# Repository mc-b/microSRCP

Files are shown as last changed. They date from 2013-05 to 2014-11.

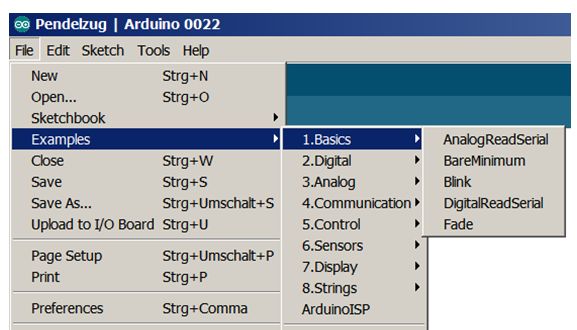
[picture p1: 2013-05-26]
microSRCP/doc/images/MicroSRCP_ArduinoIDE-howto.jpg

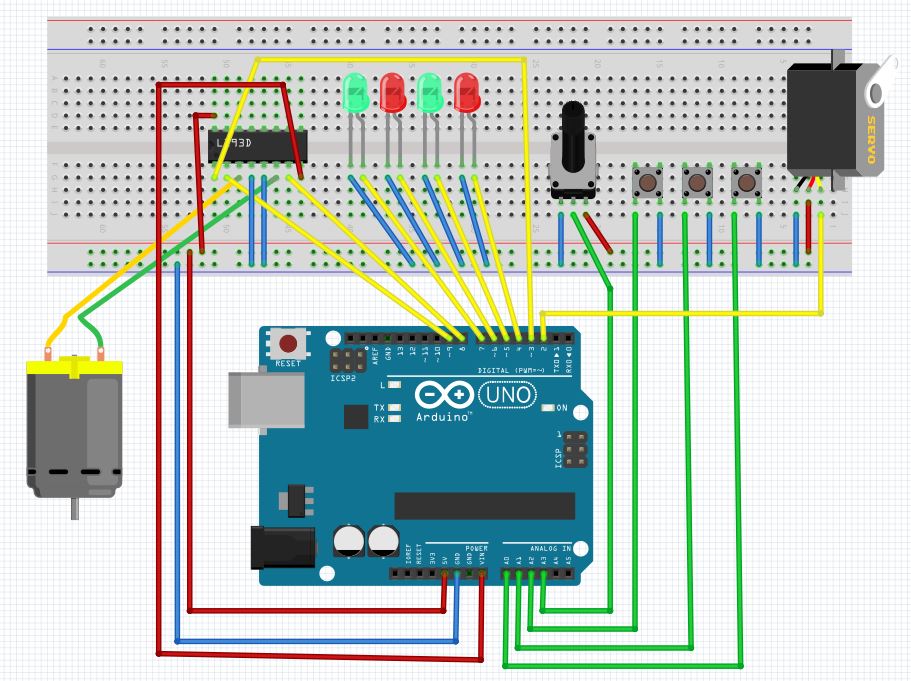
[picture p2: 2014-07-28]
microSRCP/doc/images/microSRCPV2.JPG

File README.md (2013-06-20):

microSRCP
=========

microSRCP Projekt, Steuerung einer Modelleisenbahn auf Basis der Arduino Plattform

Dieses Projekt löst das microSRCP Projekt auf berlios.de ab.

Kurzinstallation:
- Arduino Entwicklungsumgebung - http://arduino.cc/en/Main/Software, ab Version 1.0.5 installieren
- RocRail - http://wiki.rocrail.net/doku.php, zur Ansteuerung der Modelleisenbahn und der Arduino's, installieren
- Arduino Entwicklungsumgebung starten und Verzeichnis aus Menu -> Datei -> Einstellungen -> Sketchbook Speicherort notieren
- Entwicklungsumgebung beenden
- gewünschte ZIP/tar-Datei von https://github.com/mc-b/microSRCP/tags auswählen und downloaden
- ZIP/tar Datei entpacken und die Dateien aus Verzeichnis .../microSRCP/arduino in den vorher notierten Sketchbook Speicherort kopieren.
- Arduino Entwicklungsumgebung starten - unter -> Datei -> Sketchbook -> microSRCPServer wählen
- PC und Arduino mittels USB Kabel verbinden, das Betriebssystem richtet eine neue Serielle Schnittstelle ein (bei Problemen siehe www.arduino.cc)
- Unter Tools -> entsprechendes Board und Serielle Schnittstelle einstellen
- Compilieren und Uploaden des Sketches...
- RocRail starten und unter -> RocRail Eigenschaften neue srcp Zentrale mit Sub Bibliothek RS232 und gleicher Serieller Schnittstelle wie bei der Arduino Entwicklungsumgebung einrichten

Welche Arduino Boards und Shields benötigt werden steht in den entsprechenden Sketches. 

Für eine Detailierte Beschreibung, siehe https://github.com/mc-b/microSRCP/wiki.

Copyright
---------
Die Software untersteht der GNU GPL, siehe entsprechende Copyrights in 
den Sourcen. Da bedeutet u.a., sie kann frei verwendet werden, Aenderungen
und Erweiterungen muessen aber wieder frei zugaenglich sein.
Kommerzielle Produkte, ohne Offenlegung des Codes, sind damit ausgeschlossen!

Haftung
-------
Bei den Bauanleitungen bzw. irgendwelcher Software gibt es keine Haftung fuer 
irgendwelche Schaeden oder Funktionsgarantie, bitte immer nur als Anregung auffassen.
Ich hafte nicht fuer Schaeden, die der Anwender oder Dritte durch die Verwendung der 
Software oder Hardware verursachen oder erleiden. In keinem Fall hafte ich fuer 
entgangenen Umsatz oder Gewinn oder sonstige Vermoegensschaeden die bei der Verwendung 
oder durch die Verwendung dieser Programme oder Anleitungen entstehen koennen.
Und wer mit Strom umgeht, soll sich bitte bei hoeheren Spannung und Stroemen der 
Gefahren bewusst sein. Modellbahn gehoert VDE-technisch zur Kategorie Spielzeug, 
dementsprechend streng sind die Vorschriften. Siehe hierzu auch die 
Sicherheitshinweise des Fremo. 

Die Schaltungen und die Software werden als Anregung und Hilfe unter Modellbahnern
veroeffentlicht. Sie sind auf Grund von Beispielen aus dem Netz bzw. eigenen Ideen 
entstanden. Natuerlich sind sinnvolle Anregungen, Fehlermeldungen und 
Verbesserungen zu den Schaltung immer willkommen. Allerdings moechte ich aus 
gegebenen Anlass darauf hinweisen, dass ich leider keine Zeit fuer langwierige 
Diskussionen des Typs "Ich habe die Schaltung nachgebaut, warum funktioniert 
sie bei mir nicht" habe. Auch die Frage "Ich habe noch diesen oder jenen Chip 
in der Schublade, kann ich den auch verwenden", moege sich bitte jeder selbst 
beantworten. Kontaktaufnahme bitte per mail und nicht per Telefon. 
Bitte bei Problemen moeglichst exakt schildern, was wie schief geht, 
am besten mit logfiles bzw. exakter Fehlermeldung.

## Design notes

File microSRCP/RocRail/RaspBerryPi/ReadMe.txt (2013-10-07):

Konfigurations Dateien fuer RaspBerryPI
=======================================

Installation
------------
- Standard mittels NOOBS - http://www.raspberrypi.org/downloads

- Zusätzliche Packete installieren:
    sudo apt-get install tightvncserver git samba arduino
    
- Arduino anschliessen    
- Arduino Entwicklungsumgebung starten und Sketchbook Verzeichnis auf /home/pi/microSRCP/microSRCP/arduino aendern
- Entwicklungsumgebung neu starten 
- Board und Serielle Schnittstelle entsprechend Board einstellen
- Sketch microSRCPSRCPSimple compilieren und uploaden in Arduino
    
- RocRail von http://rocrail.net/software/rocrail-snapshot/ downloaden
- RocRail installieren (beim ersten Befehl kommt Fehlermeldung, ignorieren)
    sudo dpkg -i rocrail-XXXX-wheezy-armhf.deb
    sudo apt-get -f install 
    
- microSRCP Sourcen clonen oder ab https://github.com/mc-b/microSRCP/tags downloaden und entpacken
    git clone https://github.com/mc-b/microSRCP.git
    
- Dateien aus microSRCP/microSRCP/RocRail wie folgt kopieren:
    Desktop/* nach ~/Desktop
    smb.conf nach /etc/samba
- Weitere Dateien in etc/ sind Vorlagen fuer WLAN Access Point, VNCServer starten beim Systemstart etc.    
    
- microSRCP Verzeichnis öffnen für Zugriff, z.B. von Windows, via \\raspberrypi\microSRCP
    chmod -R g=u,o=u microSRCP    
    
- RaspBerryPI neu starten    
    
- X-Windows local mittels startx, oder Remote mittels vncserver und vncviewer starten
- RocRail Server und RocView starten
  
Oktober 2013 / Marcel Bernet

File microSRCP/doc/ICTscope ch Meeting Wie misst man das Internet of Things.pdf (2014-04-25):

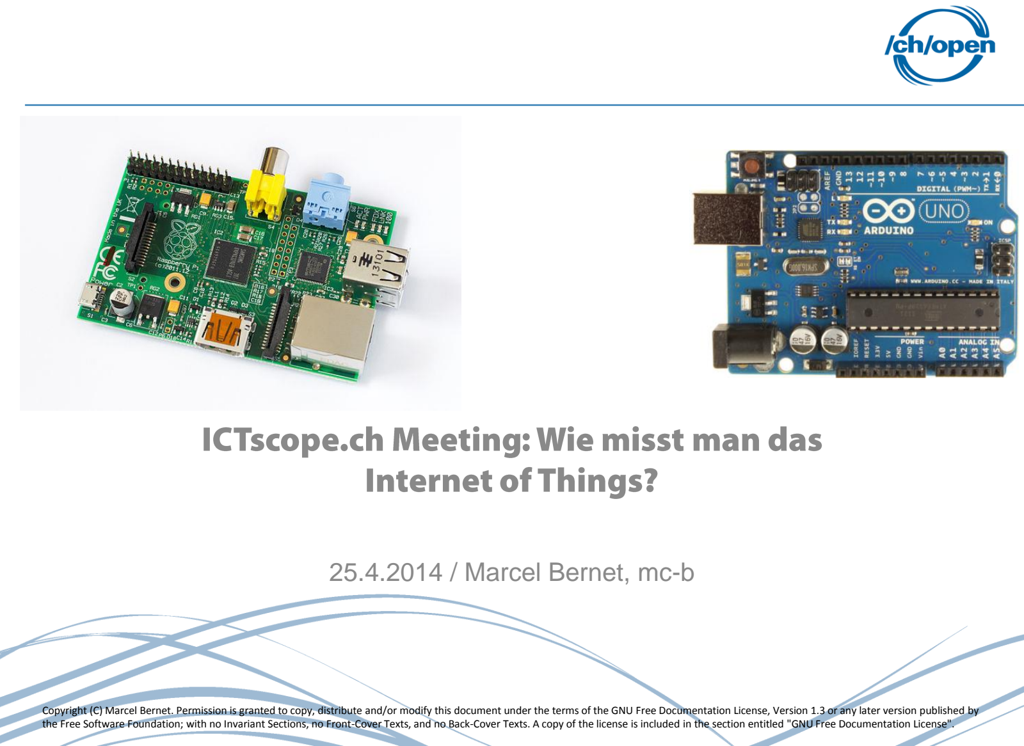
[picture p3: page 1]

Copyright (C) Marcel Bernet. Permission is granted to copy, distribute and/or modify this document under the terms of the GNU Free Documentation License, Version 1.3 or any later version published by the Free Software Foundation; with no Invariant Sections, no Front-Cover Texts, and no Back-Cover Texts. A copy of the license is included in the section entitled "GNU Free Documentation License".

# 25.4.2014 / Marcel Bernet, mc-b

# - Einleitung „Internet der Dinge“, Sensoren, Aktoren

•

# „Internet der Dinge“ Komponenten (Arduino, Raspberry Pi …)

# - „Internet der Dinge“ messen (Pendelzugsteuerung)

# - Aufbau einer Steuerung anhand einer Modelleisenbahn

# - Steuerung mit dem Internet verbinden

- Smart Cities, Pervasive Computing etc.

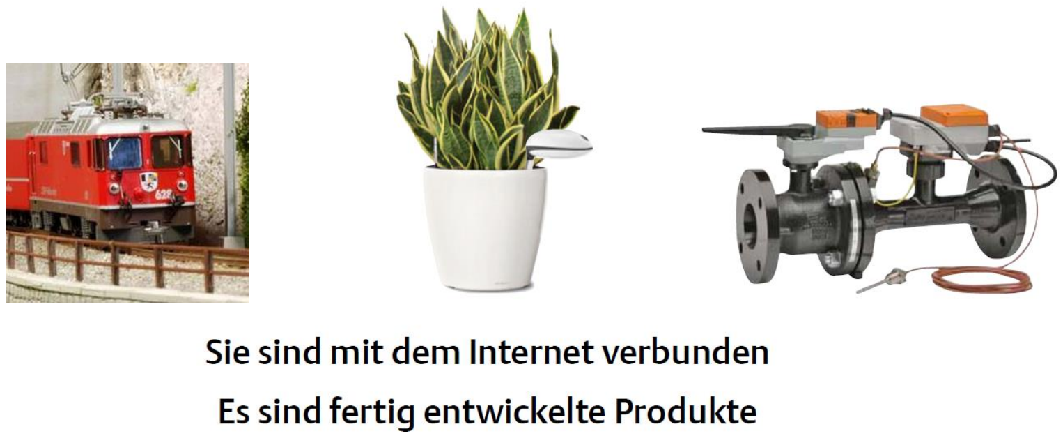
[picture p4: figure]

Quelle: /ch/open OBL vom 2.5.13 - Internet of Things @ Ergon (http://www.ch-open.ch/events/obl/oblosl-2013/)

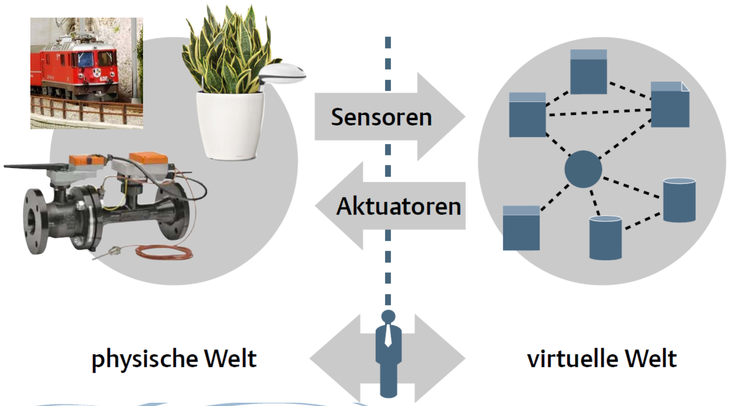
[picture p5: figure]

Quelle: /ch/open OBL vom 2.5.13 - Internet of Things @ Ergon (http://www.ch-open.ch/events/obl/oblosl-2013/)

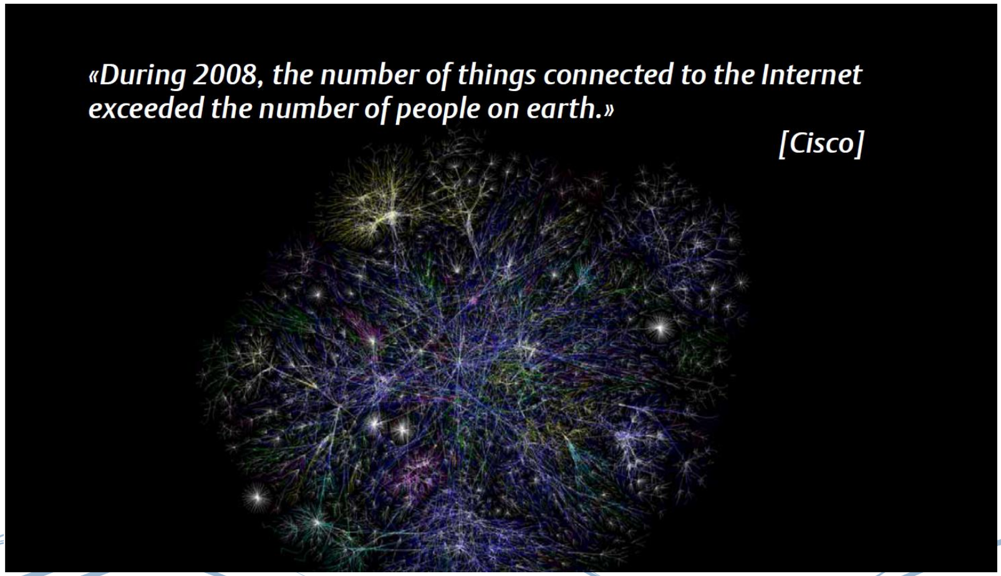
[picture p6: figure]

Quelle: /ch/open OBL vom 2.5.13 - Internet of Things @ Ergon (http://www.ch-open.ch/events/obl/oblosl-2013/)

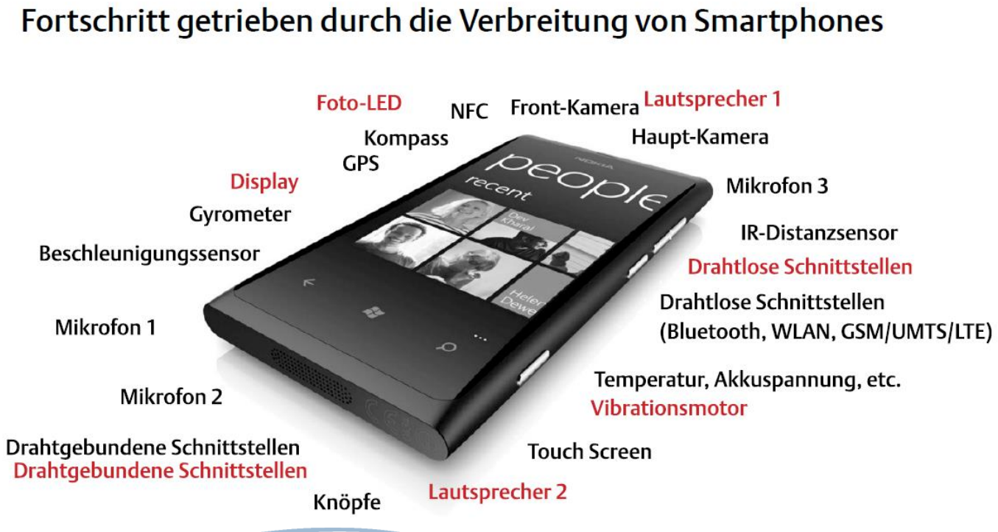
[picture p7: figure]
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

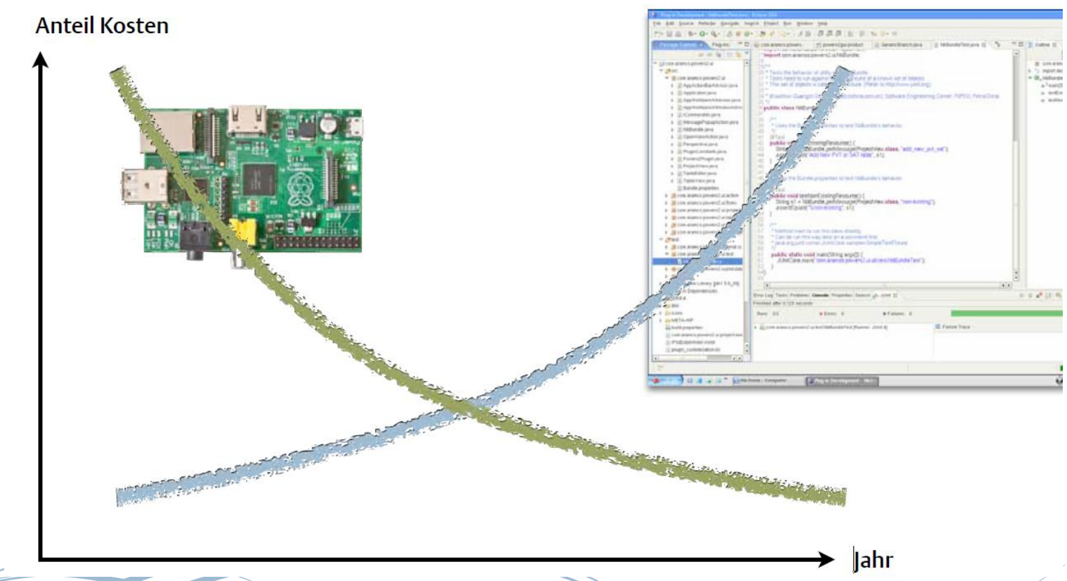
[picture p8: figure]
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

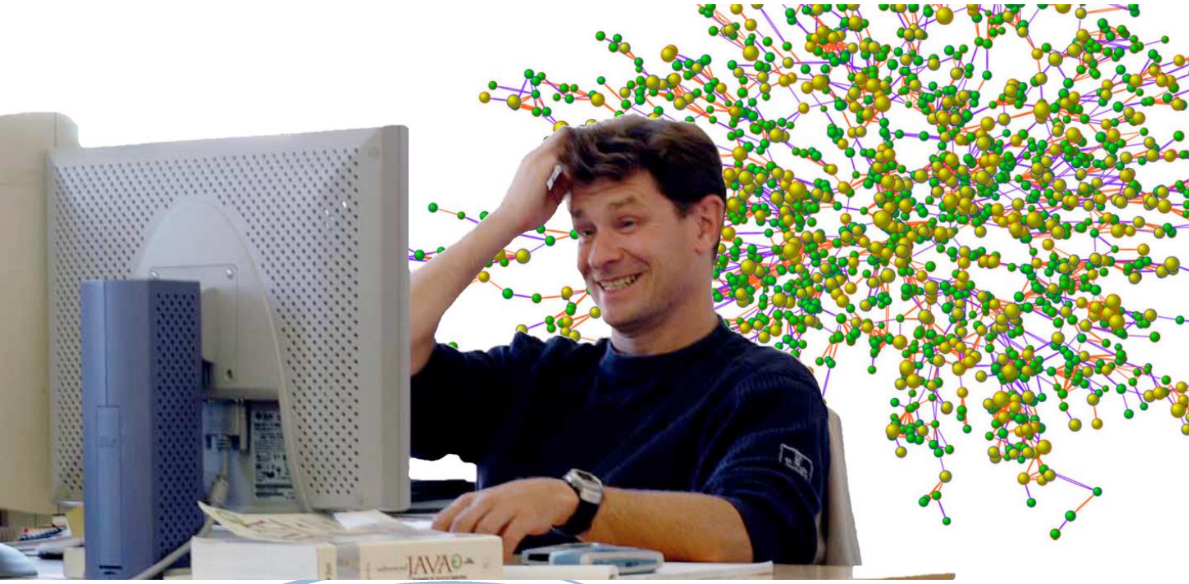
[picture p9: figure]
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

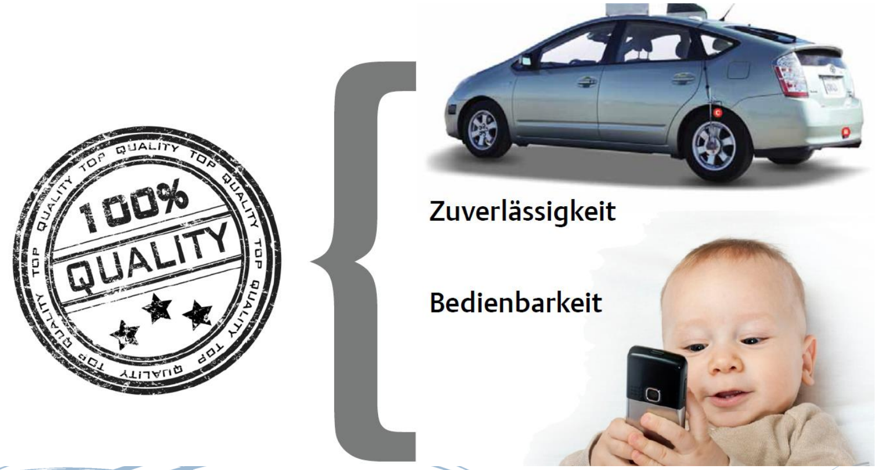
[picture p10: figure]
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

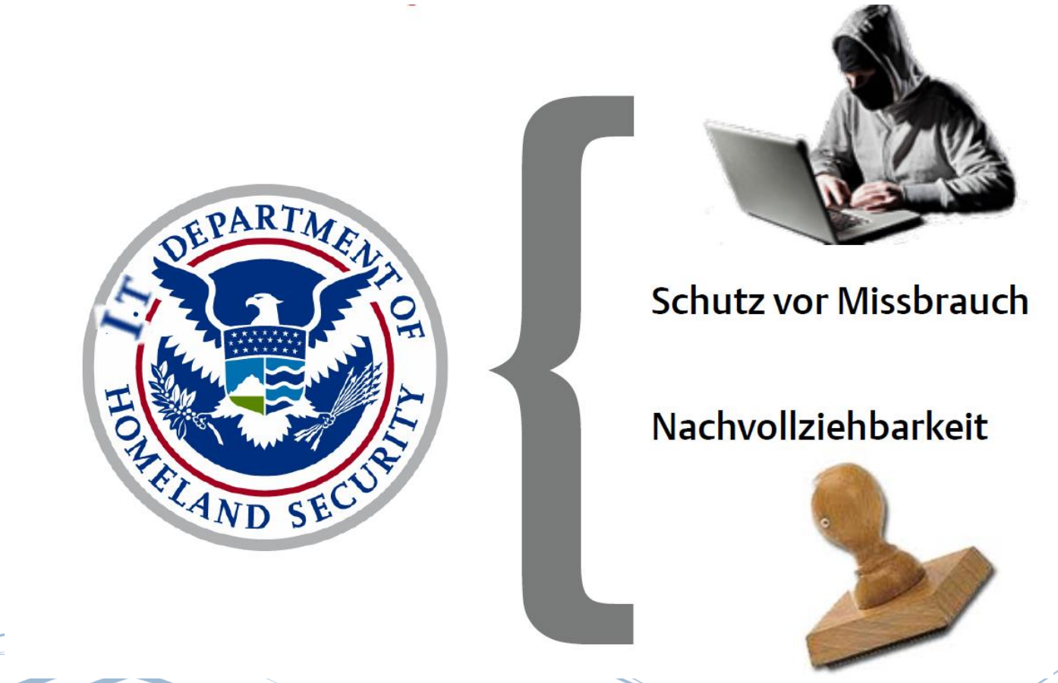
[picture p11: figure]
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

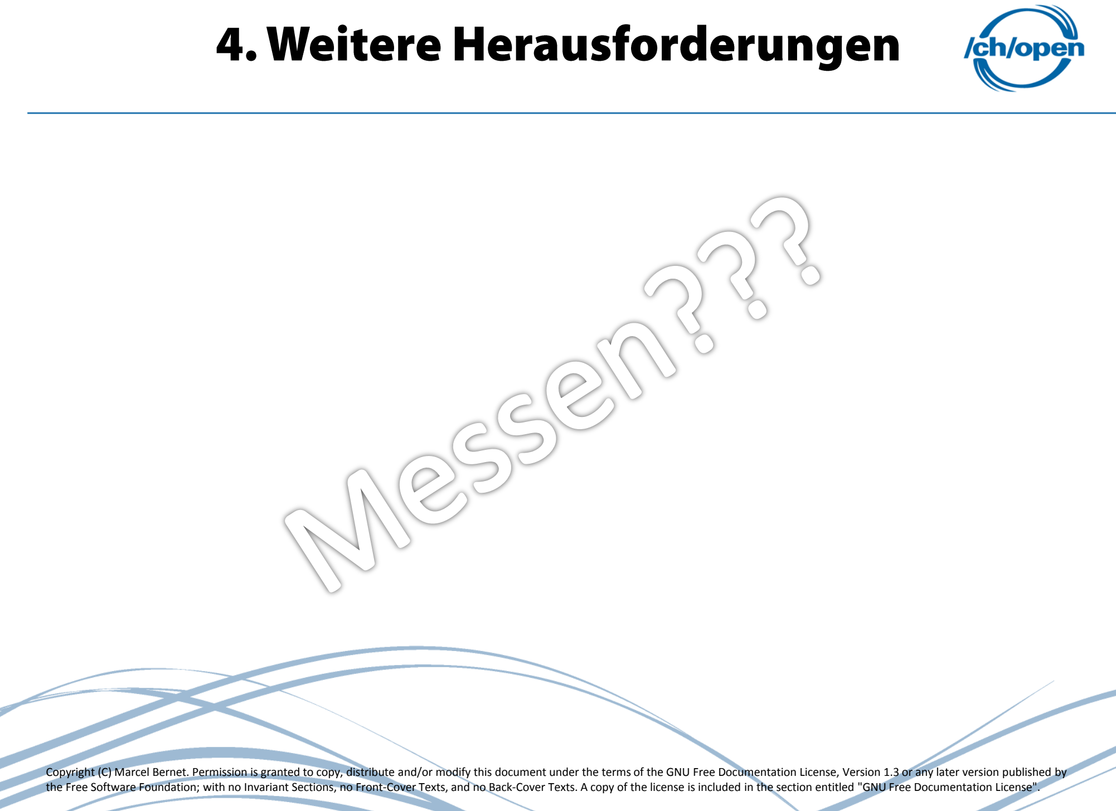
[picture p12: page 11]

# - Ein Sensor (von lateinisch sentire, dt. „fühlen“ oder „empfinden“), (Messgrößen-) Aufnehmer oder (Mess-)Fühler ist ein technisches Bauteil, das bestimmte physikalische

oder chemische Eigenschaften (z. B.: Wärmestrahlung, Temperatur, Feuchtigkeit, Druck,

# Schall, Helligkeit oder Beschleunigung) und/oder die stoffliche Beschaffenheit seiner Umgebung qualitativ oder als Messgröße quantitativ erfassen kann. Diese Größen werden mittels physikalischer oder chemischer Effekte erfasst und in ein

weiterverarbeitbares elektrisches Signal umgeformt.

- Aktoren (Wandler; Antriebselemente), oft auch wegen des englischen Begriffs „actuator“ als Aktuatoren bezeichnet, setzen die elektrischen Signale (z. B. vom Steuerungscomputer ausgehende Befehle) in mechanische Bewegung oder andere physikalische Größen (z. B. Druck oder Temperatur) um und greifen damit aktiv in das

Regelungssystem ein und/oder geben Sollgrößen vor.

- Das Internet der Dinge (auch englisch Internet of Things) beschreibt, dass der (Personal) Computer zunehmend als Gerät verschwinden und durch „intelligente Gegenstände“ ersetzt wird. Statt – wie derzeit – selbst Gegenstand der menschlichen Aufmerksamkeit zu sein, soll das „Internet der Dinge“ den Menschen bei seinen Tätigkeiten unmerklich unterstützen. Die immer kleineren Computer sollen Menschen unterstützen

ohne abzulenken oder überhaupt aufzufallen.

# - Einleitung „Internet der Dinge“, Sensoren, Aktoren

•

# „Internet der Dinge“ Komponenten (Arduino, Raspberry Pi …)

# - „Internet der Dinge“ messen (Pendelzugsteuerung)

# - Aufbau einer Steuerung anhand einer Modelleisenbahn

# - Steuerung mit dem Internet verbinden

- Smart Cities, Pervasive Computing etc.

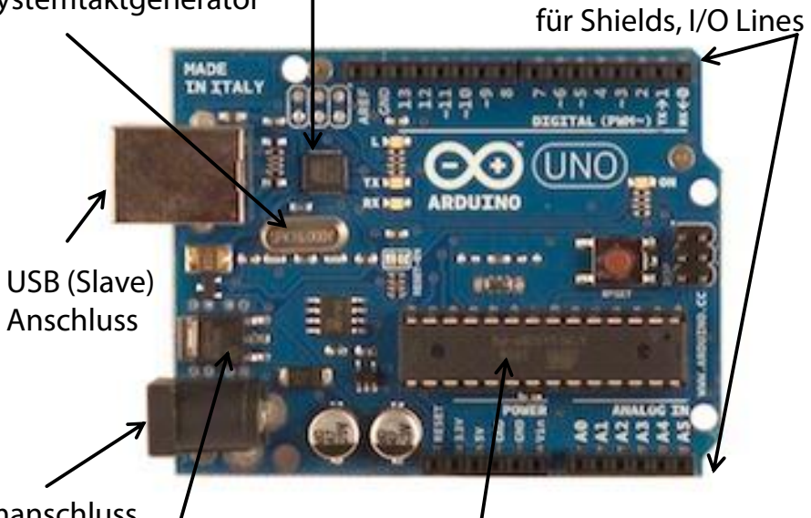
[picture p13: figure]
für Shields, I/O Lines; USB (Slave) Anschluss

# Prozessor AtMega328P 8-bit RISC Prozessor inkl. Flash, EEPROM, SRAM

# Systemtaktgenerator

# Stromanschluss 5 – 12 Volt

# Erweiterungsbuchsen

# - Die Arduino-Plattform ist eine aus Soft-und Hardware bestehende Physical-

Computing-Plattform.

# - Physical Computing bedeutet

im weitesten Sinne,

# interaktive, physische Systeme durch die Verwendung von Hardware und Software zu erstellen. Diese Systeme reagieren auf Ereignisse (Sensoren) in der realen, analogen Welt und/oder wirken (Aktoren)

auf sie ein.

## - http://de.wikipedia.org/wiki/Arduino-Plattform

# USB-to-serial driver Chip

# Spannungswandler auf 5 Volt

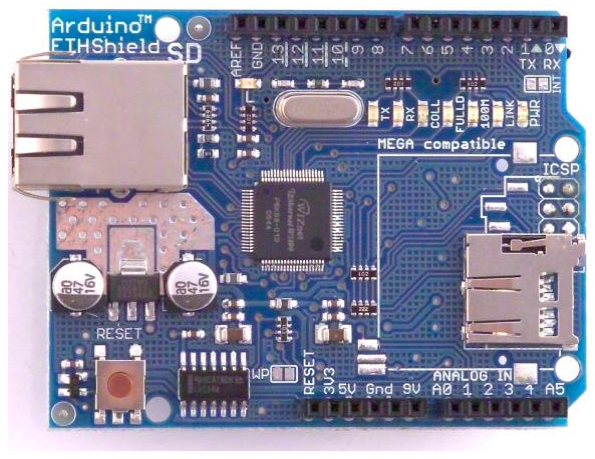
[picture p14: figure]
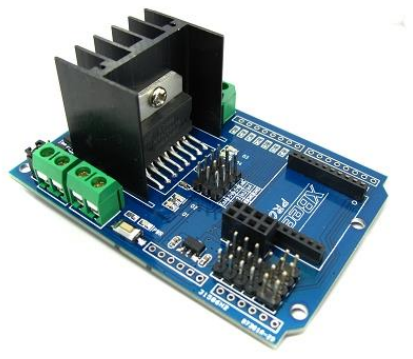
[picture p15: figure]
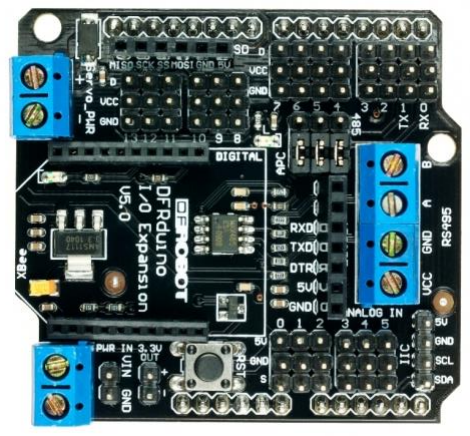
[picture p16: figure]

# - Mittels Erweiterungsboards, sogenannten Shields, kann die Funktionalität des Board

erweitert werden.

# - Diese werden einfach in die Buchsenleiste des Arduino Board gesteckt und mittels

entsprechender Software angesteuert.

# - Es existieren eine Vielzahl von Shields, u.a. für

# – Netzwerkanbindung mittels RJ45 / Ethernet

– Ansteuerung von Motoren (Lokomotiven).

# – Ein Shield zum Abspielen von Sounddateien (u.a. MP3) z.B. Für Bahnhofsdurchsagen – Schalten von 220V Verbrauchern

– IO Expansion Shields für Anschluss von Servo, LED, Rückmelder, I2C, RS 485 etc.

Ethernet-Shield | MotoMama (Motor) Shield | IO Expansion Shield

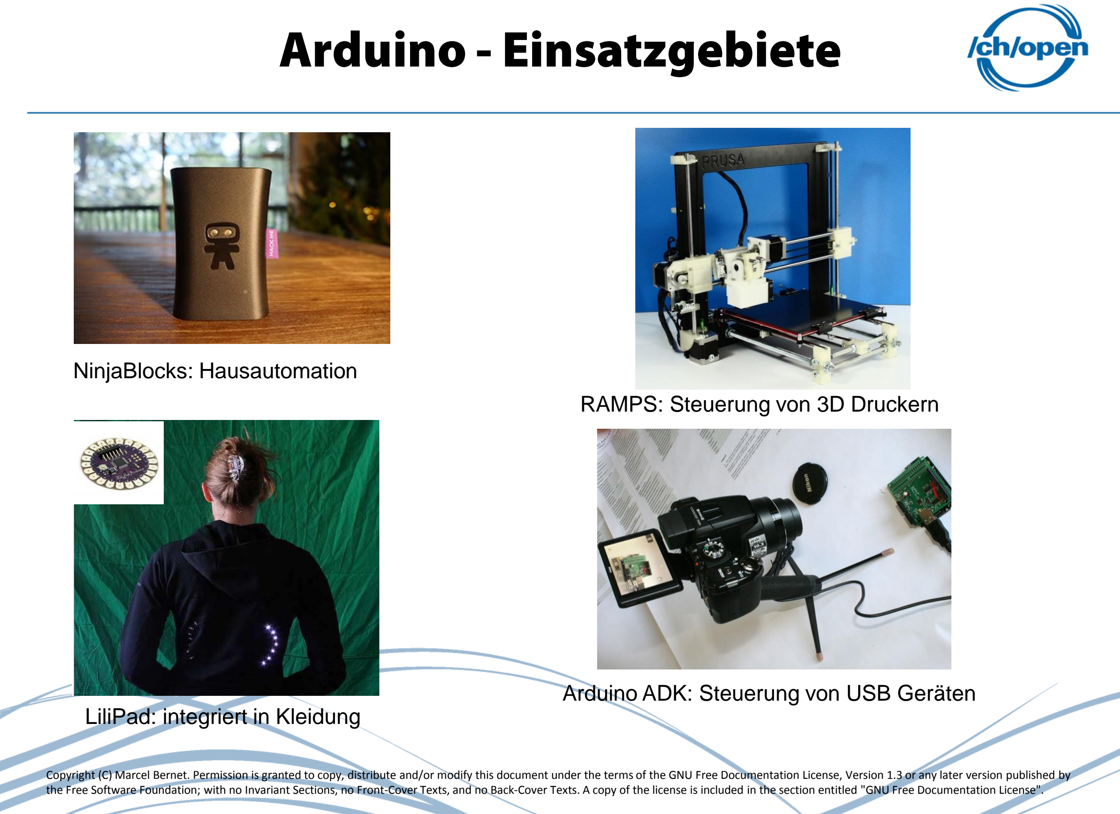
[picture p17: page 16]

## Arduino ADK: Steuerung von USB Geräten

## RAMPS: Steuerung von 3D Druckern

## LiliPad: integriert in Kleidung

## NinjaBlocks: Hausautomation

- Das microSRCP Projekt dient zum Steuern von Modelleisenbahnen.

# - Es besteht aus mehreren Sketches welche aus Arduino

Microcontrollerboards (http://www.arduino.cc/) Modelleisenbahn Zentralen macht.

# - In Verbindung mit Steuerungsprogramm RocRail, (http://www.rocrail.net/) welches auf Windows/Mac/Linux/RaspberryPi läuft, entsteht eine vollständige

Modelleisenbahn Steuerung. RocRail Clients für Smartphones(z.B. andRoc) und Tablets ergänzen die Lösung.

# - Der Raspberry Pi ist ein kreditkarten-

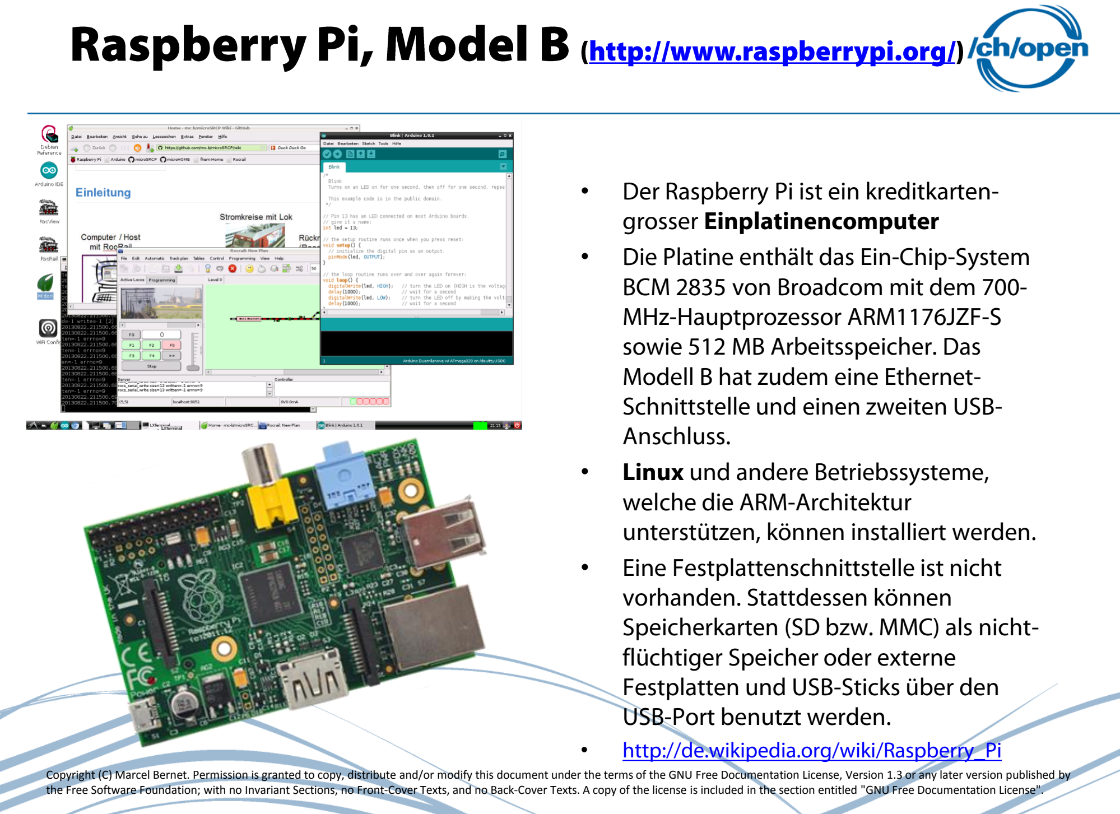
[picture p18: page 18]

# grosser Einplatinencomputer - Die Platine enthält das Ein-Chip-System BCM 2835 von Broadcom mit dem 700-MHz-Hauptprozessor ARM1176JZF-S sowie 512 MB Arbeitsspeicher. Das Modell B hat zudem eine Ethernet-Schnittstelle und einen zweiten USB-

Anschluss.
- Linux und andere Betriebssysteme,

# welche die ARM-Architektur

unterstützen, können installiert werden.

# - Eine Festplattenschnittstelle ist nicht vorhanden. Stattdessen können Speicherkarten (SD bzw. MMC) als nichtflüchtiger Speicher oder externe Festplatten und USB-Sticks über den

USB-Port benutzt werden.

# - http://de.wikipedia.org/wiki/Raspberry_Pi

# - USB, LAN, HDMI, SD Card

onBoard,

# - WLAN mittels USB Adapter anschliessbar - GPIO Port mit 26 Pin’s

– | 2 Pins eine Spannung von 5 Volt bereitstellen, aber auch genutzt werden können, um den Raspberry Pi mit Strom zu versorgen.
– | 1 Pin eine Spannung von 3,3 Volt bereitstellt
– | 1 Pin als Masse dient, sowie 4 derzeit mit der Masse verbundene Pins, die zukünftig eine andere Belegung bekommen könnten
– | 17 Pins frei programmierbar sind, wovon einige Sonderfunktionen übernehmen können
| • 5 Pins können als SPI-Schnittstelle (http://de.wikipedia.org/wiki/Serial_Peripheral_Interface) verwendet werden
| • 2 Pins haben einen 1,8-kΩ-Pull-Up-Widerstand (auf 3,3 V) und können als I 2 (http://de.wikipedia.org/wiki/I2C)C-Schnittstelle (http://de.wikipedia.org/wiki/I2C) verwendet werden
| • 2 Pins können als UART-Schnittstelle (http://de.wikipedia.org/wiki/UART) verwendet werden.

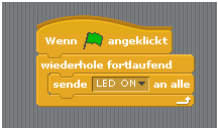
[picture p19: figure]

# - Ausbildung von Schülern und Studenten (Scratch, Python …)

# - PC Ersatz

# - Server Ersatz (kleiner Webserver, NAS etc.)

# - «Internet der Dinge» Endgerät oder Server

- Das Internet der Dinge (auch englisch Internet of Things) beschreibt,

# dass der (Personal) Computer zunehmend als Gerät verschwinden

und durch „intelligente Gegenstände“ ersetzt wird.

- Der Raspberry Pi ist ein kreditkartengrosser Einplatinencomputer.

# - Die Arduino-Plattform ist eine aus Soft-und Hardware bestehende

Physical-Computing-Plattform (I/O Gerät).

# - Kombiniert man physische Dinge (Modelleisenbahn, Lampe etc.) mit Raspberry Pi und Arduino’s – entsteht ein Netzwerk von „intelligenten

Gegenständen“ welches mit dem Internet verbunden werden kann.

# - Einleitung „Internet der Dinge“, Sensoren, Aktoren

•

# „Internet der Dinge“ Komponenten (Arduino, Raspberry Pi …)

# - „Internet der Dinge“ messen (Pendelzugsteuerung)

# - Aufbau einer Steuerung anhand einer Modelleisenbahn

# - Steuerung mit dem Internet verbinden

- Smart Cities, Pervasive Computing etc.

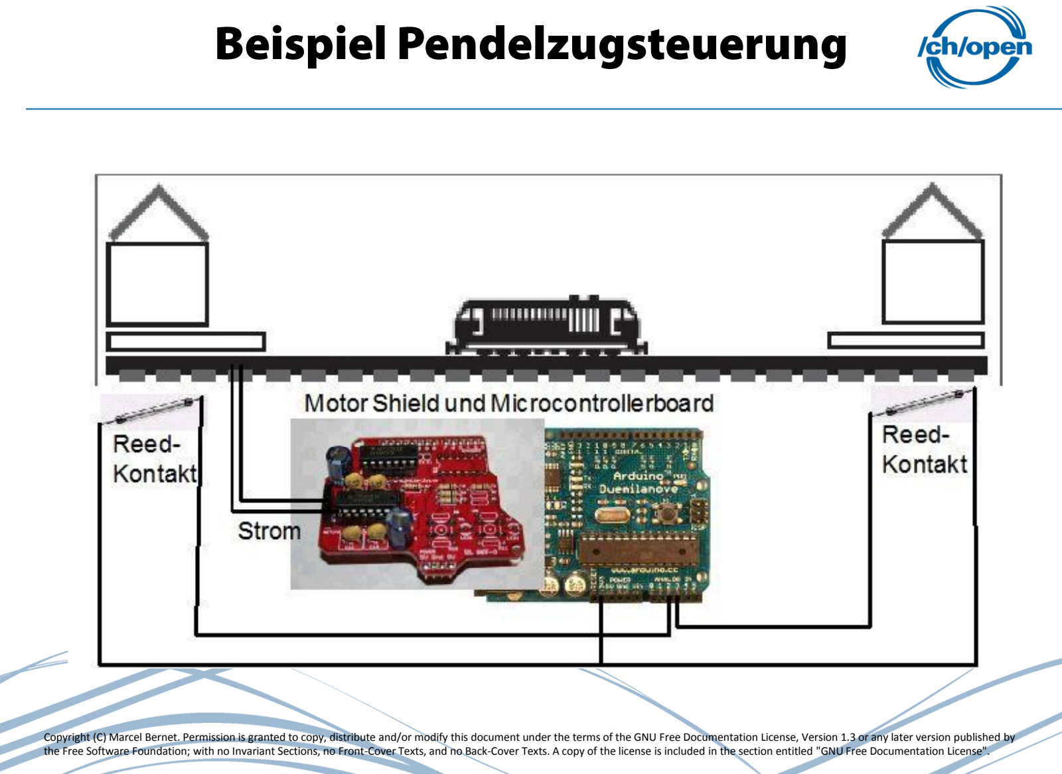
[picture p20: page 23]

void setup()

{

pinMode(dirpin1, OUTPUT); // Aktor steuert die Fahrtrichtung

pinMode(dirpin2, OUTPUT);

pinMode( sensorA, INPUT_PULLUP ); // Sensoren A und B als Input

pinMode( sensorB, INPUT_PULLUP ); // und Interne Widerstände setzen

}

void loop()

{

digitalWrite(dirpin1,HIGH); // Aktor Fahrrichtung vorwaerts

digitalWrite(dirpin2,LOW);
analogWrite(speedpin, speed); // Geschwindigkeit

while (digitalRead( sensorA) != 0 ) // Loop bis SensorA aktiviert wird

delay( 10 );

analogWrite(speedpin, 0); // Stop

delay(1000); // 1 Sekunden Wartezeit

digitalWrite(dirpin1,LOW); // Aktor Fahrrichtung rueckwaerts

digitalWrite(dirpin2,HIGH);
analogWrite(speedpin, speed); // Geschwindigkeit

while (digitalRead( sensorB) != 0 ) // Loop bis SensorA aktiviert wird

delay( 10 );
analogWrite(speedpin, 0); // Stop

delay(1000); // 1 Sekunden Wartezeit

}

void setup()

{
pinMode(dirpin1, OUTPUT); // Aktor steuert die Fahrtrichtung

…
pinMode(rot, OUTPUT);
pinMode(gruen, OUTPUT);

}

void loop()

{
digitalWrite(dirpin1,HIGH); // Aktor Fahrrichtung vorwaerts

digitalWrite(dirpin2,LOW);
analogWrite(speedpin, speed); // Geschwindigkeit

while (digitalRead( sensorA) != 0 ) // Loop bis SensorA aktiviert wird

delay( 10 );
analogWrite(speedpin, 0); // Stop
digitalWrite(gruen, HIGH); // freie Fahrt

digitalWrite(rot, LOW);

delay(1000); // 1 Sekunden Wartezeit

digitalWrite(dirpin1,LOW); // Aktor Fahrrichtung rueckwaerts

digitalWrite(dirpin2,HIGH);
analogWrite(speedpin, speed); // Geschwindigkeit

while (digitalRead( sensorB) != 0 ) // Loop bis SensorA aktiviert wird

delay( 10 );
analogWrite(speedpin, 0); // Stop
// dito wie oben, aber umgekehrte Werte

delay(1000); // 1 Sekunden Wartezeit

}

# 2 Entry (E) + 2 eXit (X) + 1 Read (R) + 1 Write (W) = 6 CFP

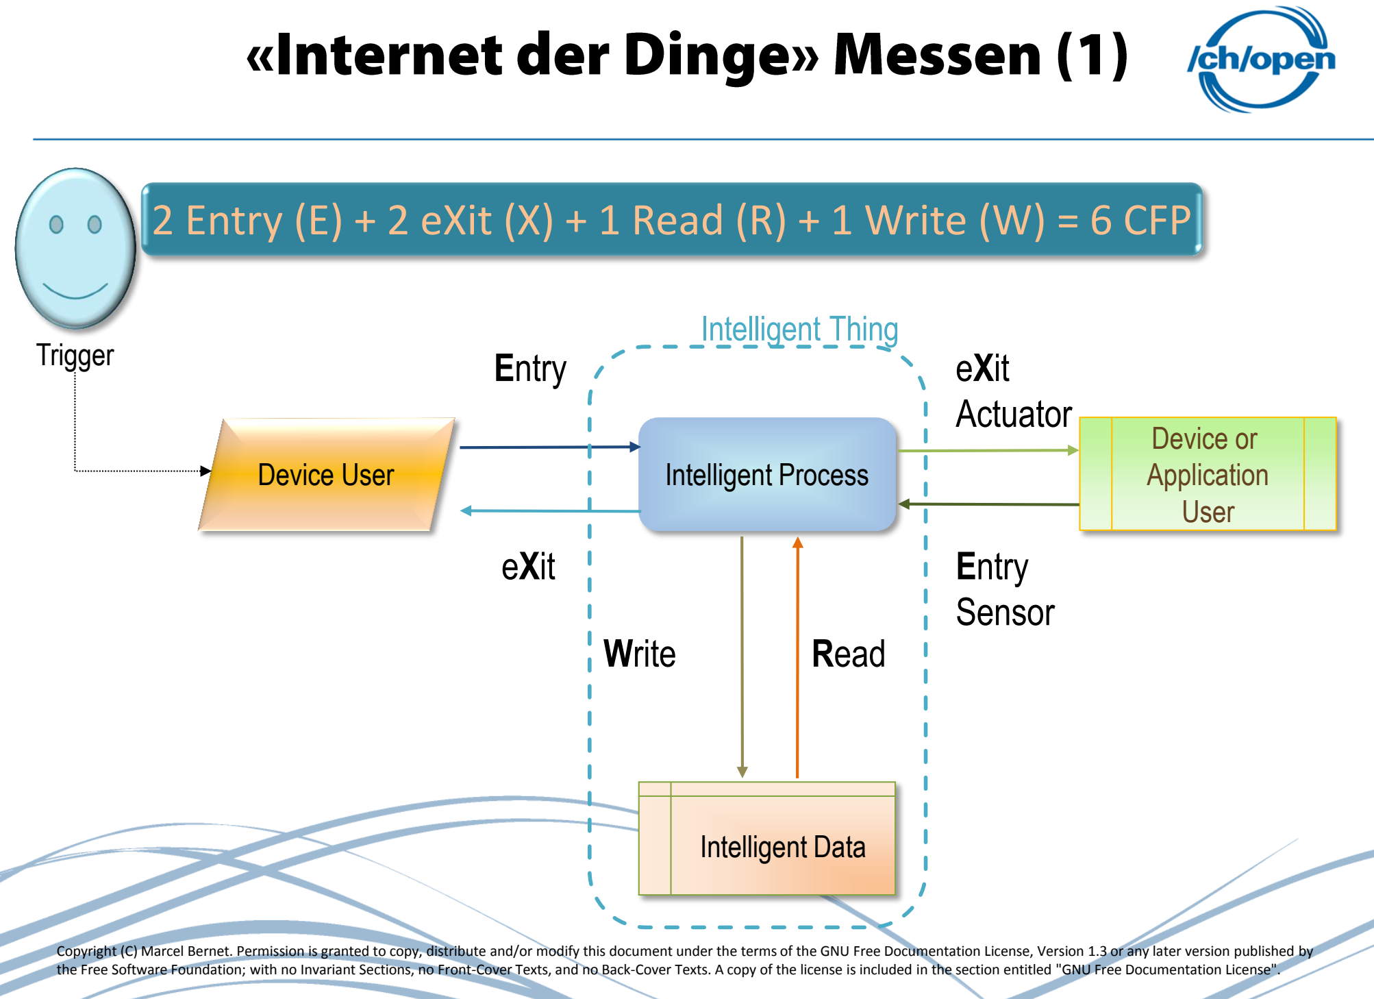
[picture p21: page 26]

# Intelligent Process

# Intelligent Data

# Device or Application User

# Device User

Trigger | Entry | eXit Actuator

# eXit

Write | Read

# Entry Sensor

# Intelligent Thing

# - Einleitung „Internet der Dinge“, Sensoren, Aktoren

•

# „Internet der Dinge“ Komponenten (Arduino, Raspberry Pi …)

•

# „Internet der Dinge“ messen (Pendelzugsteuerung)

# - Aufbau einer Steuerung anhand einer Modelleisenbahn

# - Steuerung mit dem Internet verbinden

- Smart Cities, Pervasive Computing etc.

# - Server welche die Clients überwacht und steuert

# - Protokoll zwischen Client und Server - Clients welche die Befehle

# vom Server entgegennehmen und weiterleiten an - Sensoren und Aktoren

– Reedkontakte, LED, Servo’s, Motoren etc.

# - Eingabegeräte wie:

# – PC Programm oder APP’s auf dem Smartphone

# Clients

# Protokoll

# Eingabegeräte

# Sensoren und Aktoren

# - Modelleisenbahn Komponenten

# – Server: RaspberryPi/RocRail – Client: Arduino/microSRCPServer – Protokoll: SRCP – Sensoren und Aktoren = Geräte

– Eingabegeräte: RocView, andRoc,

# iRoc …

# - https://github.com/mc-b/microSRCP/wiki - http://de.wikipedia.org/wiki/Rocrail - http://srcpd.sourceforge.net/

# - Rocrail ist eine freie Software zur Steuerung von digitalen Modelleisenbahnen. Die Züge können manuell, voll-automatisch oder in

einem Mischbetrieb gesteuert werden.

# - Hausautomation Komponenten

# – Server: RaspberryPi/fhem – Client: Arduino/StandardFirmata – Protokoll: Firmata – Sensoren und Aktoren = Arduino Pin’s – Eingabegeräte: Browser, andFhem …

## - http://www.fhemwiki.de/wiki/Arduino - http://de.wikipedia.org/wiki/FHEM - http://firmata.org/wiki/Main_Page

# - FHEM ist ein Perl-basiertes Serverprogramm für die Hausautomation, der zur automatisierten Bedienung von Aktoren wie zum Beispiel Lichtschaltern oder Heizung sowie der Aufzeichnung von Sensorinformationen wie Raum-

temperatur oder Luftfeuchtigkeit dient.

# - Rocrail ist eine freie Software zur Steuerung von digitalen Modelleisenbahnen. Die Züge können manuell, voll-automatisch oder in einem

Mischbetrieb gesteuert werden.
- Es verwaltet Lokomotiven,

# Sensoren, Signale etc. in

Tabellen.

# - Bietet einen komfortablen Gleisplaneditor - Und bietet Automatische

Abläufe mittels Blöcken,
Fahrstrassen und Fahrplänen.

# - Lässt sich mittels Smartphone

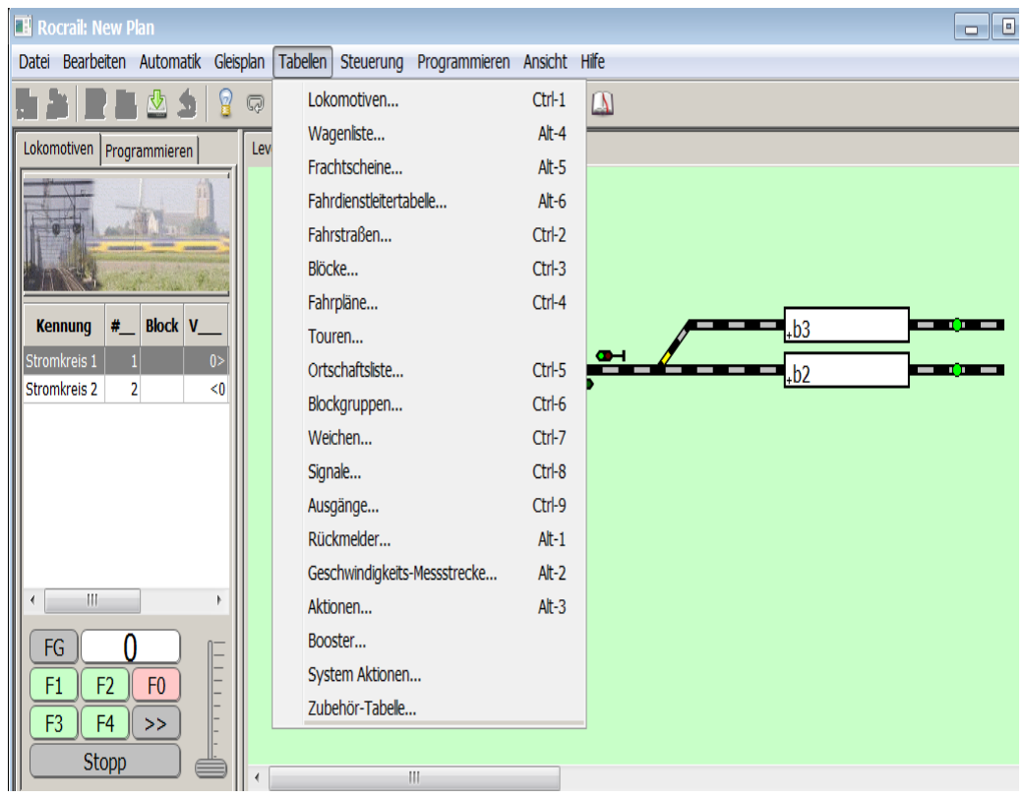
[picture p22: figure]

# aus dem Internet bedienen. http://wiki.rocrail.net/doku.php?id=stepbystep-de

# - Kombiniert man phyische Dinge (Modelleisenbahn, Lampe etc.) mit Raspberry Pi und Arduino’s – entsteht ein Netzwerk von „intelligenten

Gegenständen“ welches mit dem Internet verbunden werden kann.

# Sensoren und Aktoren

# - Der Grundsätzliche Aufbau ist um einen Arduino mit Motor Shield ergänzt, welcher ein

DCC Signal erzeugt.

# - Jede Lokomotive muss mit einem DCC Decoder ausgerüstet sein und bekommt eine eindeutige

Adresse zugewiesen.

# - An der Schaltung von LED’s und Servo’s und die Rückmeldung der Sensoren, wird nichts

verändert.

# - Jede Zentrale/Clients muss in RocRail mit einer eindeutigen Kennung erfasst und die dazugehörenden Aktoren und Sensoren mittels

Schnittstellenkennung zugewiesen werden.

# Server / Host

# Clients

# SRCP Protokoll

# Eingabegeräte

## Sensoren und Aktoren

# DCC Zentrale

# http://www.opendcc.de/info/dcc/dcc.html

# DCC Protokoll

# - Einleitung „Internet der Dinge“, Sensoren, Aktoren

•

# „Internet der Dinge“ Komponenten (Arduino, Raspberry Pi …)

# - „Internet der Dinge“ messen (Pendelzugsteuerung)

# - Aufbau einer Steuerung anhand einer Modelleisenbahn

# - Steuerung mit dem Internet verbinden

- Smart Cities, Pervasive Computing etc.

# - Dynamisches DNS oder DDNS ist

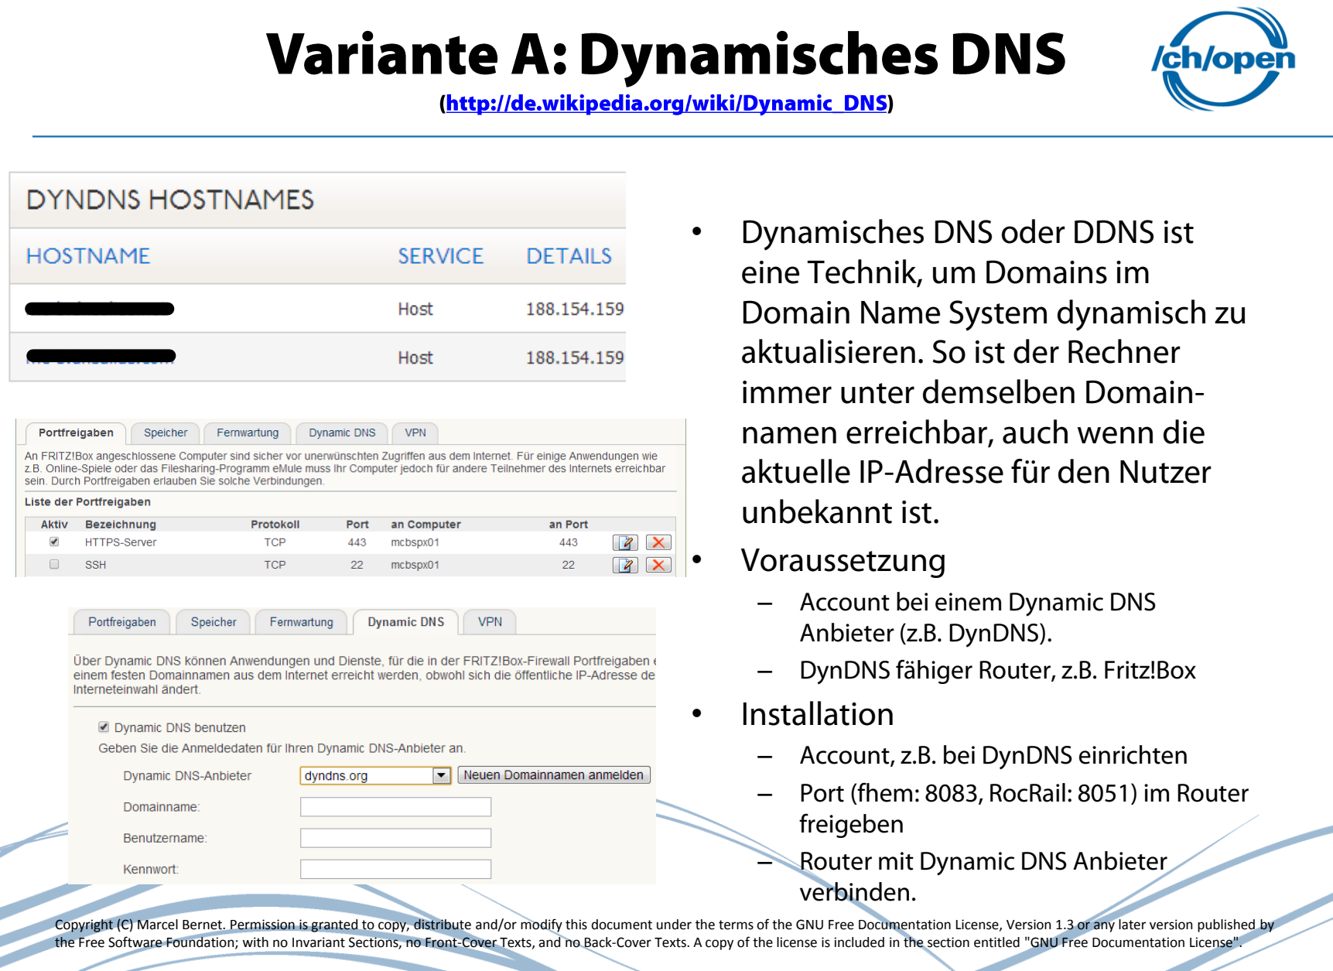
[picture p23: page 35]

# eine Technik, um Domains im Domain Name System dynamisch zu aktualisieren. So ist der Rechner immer unter demselben Domainnamen erreichbar, auch wenn die aktuelle IP-Adresse für den Nutzer

unbekannt ist.

# - Voraussetzung

# – Account bei einem Dynamic DNS

Anbieter (z.B. DynDNS).

# – DynDNS fähiger Router, z.B. Fritz!Box

# - Installation

# – Account, z.B. bei DynDNS einrichten – Port (fhem: 8083, RocRail: 8051) im Router freigeben – Router mit Dynamic DNS Anbieter

verbinden.

# - Verbindung erfolgt vom

lokalen Gerät in die Cloud.

# Eine Verbindung Cloud –> Gerät ist ausgeschlossen

(Security).

# - Vorgehen (Grob)

# – Account bei Cloud Anbieter lösen – Gerät(e) eintragen – Client Software und i.d.R. Key herunterladen – Software auf Geräte laden

und mit Cloud verbinden.

# - Einleitung „Internet der Dinge“, Sensoren, Aktoren

•

# „Internet der Dinge“ Komponenten (Arduino, Raspberry Pi …)

# - „Internet der Dinge“ messen (Pendelzugsteuerung)

# - Aufbau einer Steuerung anhand einer Modelleisenbahn

# - Steuerung mit dem Internet verbinden

- Smart Cities, Pervasive Computing etc.

# - Smarter Cities – wie schafft eine Stadt oder eine Region dank intelligenten Systemen mehr Lebensqualität für ihre Bürger und schont dabei erst noch die Ressourcen ?

Quelle: eCH GV vom 10.4.2104 - http://www.ech.ch/vechweb/page?p=page&site=/Gremien/Generalversammlung/2014

Quelle: eCH GV vom 10.4.2104 - http://www.ech.ch/vechweb/page?p=page&site=/Gremien/Generalversammlung/2014

Quelle: eCH GV vom 10.4.2104 - http://www.ech.ch/vechweb/page?p=page&site=/Gremien/Generalversammlung/2014

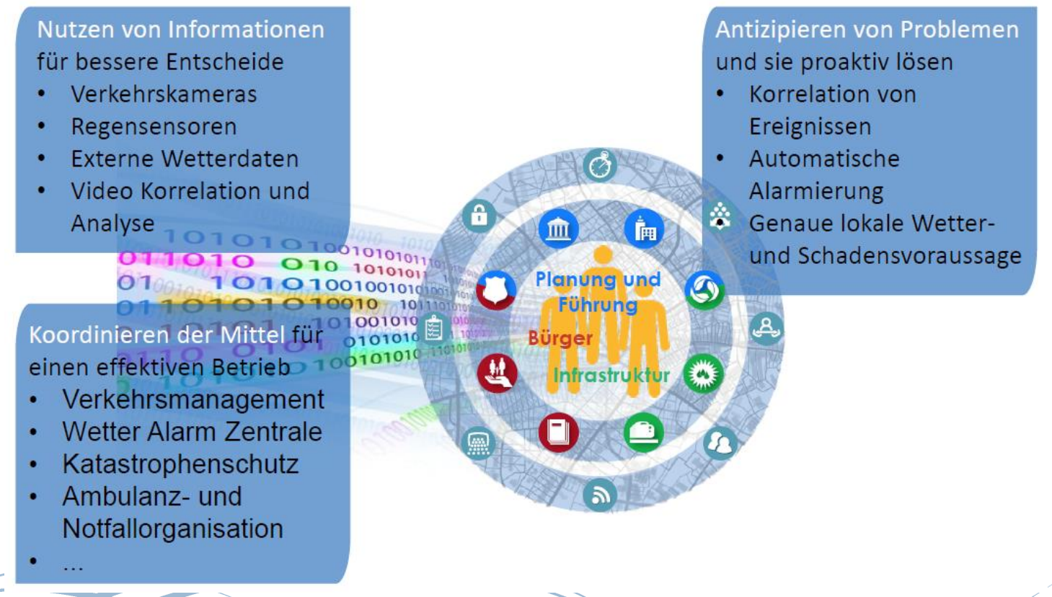
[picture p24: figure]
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

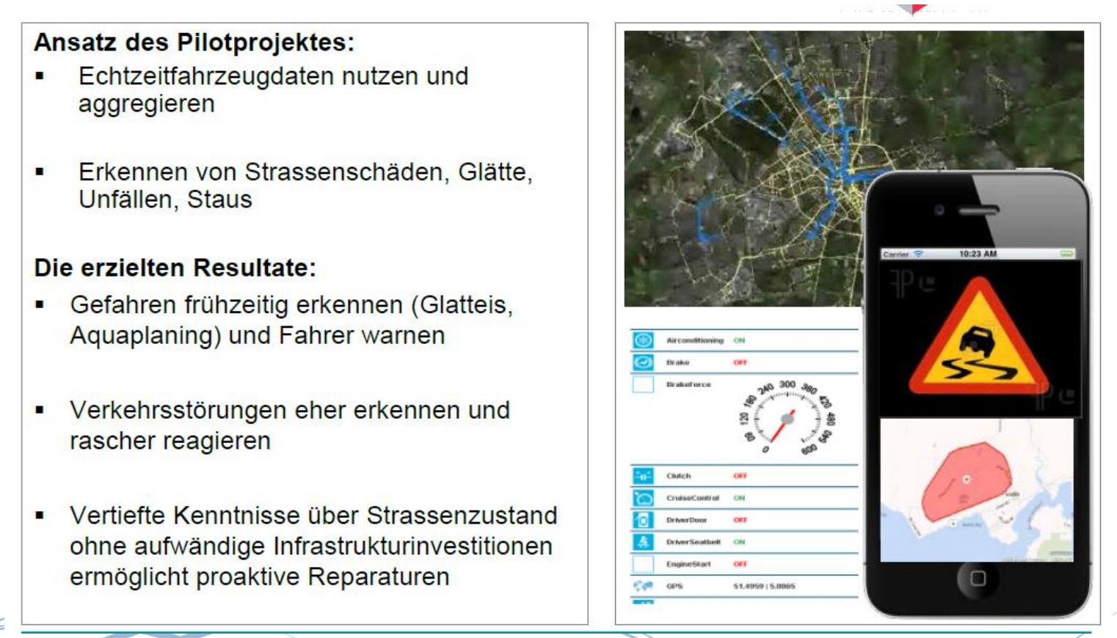
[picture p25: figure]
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

- Der Begriff Pervasive computing (aus engl. (http://de.wikipedia.org/wiki/Englische_Sprache) pervasive, ‚durchdringend‘,

# ‚um sich greifend‘, und computing, ‚Computerwesen‘, ‚EDV‘) bzw. Rechnerdurchdringung bezeichnet die alles durchdringende

Vernetzung (http://de.wikipedia.org/wiki/Rechnernetz) des Alltags durch den Einsatz „intelligenter“ Gegenstände.

# - Quelle: http://de.wikipedia.org/wiki/Pervasive_computing

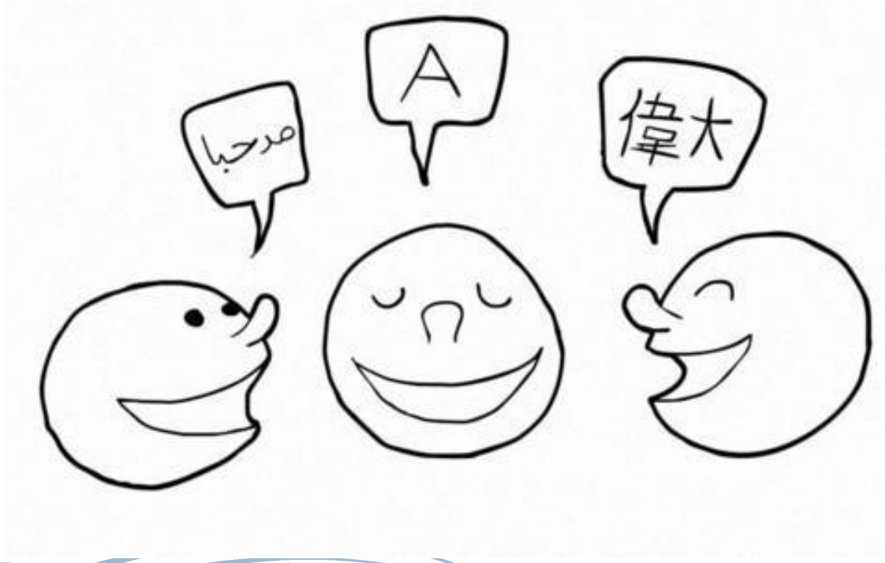
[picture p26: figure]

# - Arduino

# – http://www.arduino.cc - Hauptseite – http://forum.arduino.cc/ - Forum

– http://playground.arduino.cc// (http://playground.arduino.cc/Deutsch/HomePage)Deutsch/HomePage (http://playground.arduino.cc/Deutsch/HomePage) - Playground

# - fhem

# – http://fhem.de/fhem_DE.html - Hauptseite – http://forum.fhem.de/ - Forum – http://www.fhemwiki.de/wiki/Hauptseite - Wiki

# - microSRCP

# – https://github.com/mc-b/microSRCP/wiki - Wiki – https://github.com/mc-b/microSRCP - Code – http://forum.rocrail.net/viewtopic.php?t=5930&highlight= - Forum RocRail

# - Raspberry Pi

# – http://www.raspberrypi.org/ - Hauptseite – http://www.elinux.org/R-Pi_Hub - Wiki – http://www.raspberrypi.org/phpBB3/ - Forum

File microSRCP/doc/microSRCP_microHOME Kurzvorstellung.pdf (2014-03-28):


Copyright (C) mc-b, Marcel Bernet. Das Dokument ist unter der Lizenz „Creative Commons Attribution/Share Alike“ verfügbar. | Folie 1

mc-b, Marcel Bernet


Copyright (C) mc-b, Marcel Bernet. Das Dokument ist unter der Lizenz „Creative Commons Attribution/Share Alike“ verfügbar. | Folie 2

## - Personen welche sich in die Welt der «Vernetzten Dinge» einarbeiten wollen

– Anfangs erstmal einen großen Dank an Marcel. Ich finde die Zusammenführung von Rocrail und Arduino mittels SRCP einfach Klasse. Und das Ganze mit Code und Dokumentierung zu veröffentlichen ist natürlich das Beste
daran - http://forum.rocrail.net/viewtopic.php?f=47&t=5930&start=45

## - Personen welche ein «fertiges» Produkt benötigen

– Wo sind die CV Einstellungen für …

## - Server welche die Clients

Copyright (C) mc-b, Marcel Bernet. Das Dokument ist unter der Lizenz „Creative Commons Attribution/Share Alike“ verfügbar.; Folie 3; Server / Host; Clients; Protokoll; Eingabegeräte

überwacht und steuert
• Protokoll zwischen Client
und Server
• Clients welche die Befehle
vom Server entgegen-
nehmen und weiterleiten an
• Sensoren und Aktoren
– Readkontakte, LED, Servo’s,
Motoren etc.
• Eingabegeräte wie:
– PC Programm oder APP’s auf
dem Smartphone

Sensoren und Aktoren


Copyright (C) mc-b, Marcel Bernet. Das Dokument ist unter der Lizenz „Creative Commons Attribution/Share Alike“ verfügbar. | Folie 4
- Das microSRCP Projekt dient zum Steuern von Modelleisenbahnen.
- Es besteht aus mehreren Sketches welche aus Arduino Microcontrollerboards (http://www.arduino.cc/) Modelleisenbahn Zentralen macht.
- In Verbindung mit Steuerungsprogramm RocRail, (http://www.rocrail.net/) welches auf Windows/Mac/Linux/RaspberryPi läuft, entsteht eine vollständige Modelleisenbahn Steuerung. RocRail Clients für Smartphones(z.B. andRoc) und Tablets ergänzen die Lösung.


Copyright (C) mc-b, Marcel Bernet. Das Dokument ist unter der Lizenz „Creative Commons Attribution/Share Alike“ verfügbar. | Folie 5
- FHEM ist Serverprogramm für die Hausautomation, das zur Automatisierung von Lichtschaltern oder Heizung und Aufzeichnung von Sensorinformationen wie Raum-temperatur oder Luftfeuchtigkeit dient.
- Das microHOME Projekt beschreibt Schritt für Schritt den Aufbau einer "Do-it YourSelf" Heimautomatisierung.
- microHOME basiert auf Modernen Microcomputern (Raspberry (http://www.raspberrypi.org/) Pi) (http://www.raspberrypi.org/) und I/O Boards (Arduino). (http://www.arduino.cc/) Ergänzt durch Open Source Software(z.B.FHEM), (http://fhem.de/) einfache Scripts und kleine C/C++ Programme.
- http://fhem.de/fhem_DE.html
- http://www.fhemwiki.de/wiki/Arduino
- https://github.com/mc-b/microHOME/wiki

Wiki - microSRCP | Wiki - microHOME


Copyright (C) mc-b, Marcel Bernet. Das Dokument ist unter der Lizenz „Creative Commons Attribution/Share Alike“ verfügbar. | Folie 6
https://github.com/mc-b/microSRCP/wiki | https://github.com/mc-b/microHOME/wiki

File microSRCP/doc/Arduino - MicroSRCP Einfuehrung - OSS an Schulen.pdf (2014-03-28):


Copyright (C) Marcel Bernet. Permission is granted to copy, distribute and/or modify this document under the terms of the GNU Free Documentation License, Version 1.3 or any later version published by the Free Software Foundation; with no Invariant Sections, no Front-Cover Texts, and no Back-Cover Texts. A copy of the license is included in the section entitled "GNU Free Documentation License".

# Marcel Bernet, mc-b

- Bei den Bauanleitungen bzw. irgendwelcher Software gibt es keine Haftung für irgendwelche Schäden oder Funktionsgarantie, bitte immer nur als Anregung auffassen.
- Ich hafte nicht für Schäden, die der Anwender oder Dritte durch die Verwendung der Software oder Hardware verursachen oder erleiden. In keinem Fall hafte ich für entgangenen Umsatz oder Gewinn

# oder sonstige Vermögensschäden die bei der Verwendung oder durch die Verwendung dieser

Programme oder Anleitungen entstehen können.
- Und wer mit Strom umgeht, soll sich bitte bei höheren Spannung und Strömen der Gefahren bewusst sein. Modellbahn gehört VDE-technisch zur Kategorie Spielzeug, dementsprechend streng sind die Vorschriften.
- Siehe hierzu auch die Sicherheitshinweise des Fremo.
- Die Schaltungen und die Software werden als Anregung und Hilfe unter Modellbahnern veröffentlicht. Sie sind auf Grund von Beispielen aus dem Netz bzw. eigenen Ideen entstanden.
- Natürlich sind sinnvolle Anregungen, Fehlermeldungen und Verbesserungen zu den Schaltung immer willkommen. Allerdings möchte ich aus gegebenen Anlass darauf hinweisen, dass ich leider keine Zeit für langwierige Diskussionen des Typs "Ich habe die Schaltung nachgebaut, warum funktioniert sie bei mir nicht" habe. Auch die Frage "Ich habe noch diesen oder jenen Chip in der Schublade, kann ich den auch verwenden", möge sich bitte jeder selbst beantworten.

# – Einleitung „Internet der Dinge“, Sensoren, Aktoren – 5′

# – Die Arduino Plattform (Hardware, einfache Anwendungen, Sensoren) – 45′

# – Die Raspberry Pi Plattform – 5′ – Arduino’s und Raspberry Pi verbinden – 5′ – Aufbau einer Steuerung anhand zweier konkreter Beispiele (Hausautomation und Modelleisenbahn-Steuerung) – 60′


Quelle: /ch/open OBL vom 2.5.13 - Internet of Things @ Ergon (http://www.ch-open.ch/events/obl/oblosl-2013/)


Quelle: /ch/open OBL vom 2.5.13 - Internet of Things @ Ergon (http://www.ch-open.ch/events/obl/oblosl-2013/)

# - Ein Sensor (von lateinisch sentire, dt. „fühlen“ oder „empfinden“), (Messgrößen-) Aufnehmer oder (Mess-)Fühler ist ein technisches Bauteil, das bestimmte physikalische

oder chemische Eigenschaften (z. B.: Wärmestrahlung, Temperatur, Feuchtigkeit, Druck,

# Schall, Helligkeit oder Beschleunigung) und/oder die stoffliche Beschaffenheit seiner Umgebung qualitativ oder als Messgröße quantitativ erfassen kann. Diese Größen werden mittels physikalischer oder chemischer Effekte erfasst und in ein

weiterverarbeitbares elektrisches Signal umgeformt.

- Aktoren (Wandler; Antriebselemente), oft auch wegen des englischen Begriffs „actuator“ als Aktuatoren bezeichnet, setzen die elektrischen Signale (z. B. vom Steuerungscomputer ausgehende Befehle) in mechanische Bewegung oder andere physikalische Größen (z. B. Druck oder Temperatur) um und greifen damit aktiv in das

Regelungssystem ein und/oder geben Sollgrößen vor.

- Das Internet der Dinge (auch englisch Internet of Things) beschreibt, dass der (Personal) Computer zunehmend als Gerät verschwinden und durch „intelligente Gegenstände“ ersetzt wird. Statt – wie derzeit – selbst Gegenstand der menschlichen Aufmerksamkeit zu sein, soll das „Internet der Dinge“ den Menschen bei seinen Tätigkeiten unmerklich unterstützen. Die immer kleineren Computer sollen Menschen unterstützen

ohne abzulenken oder überhaupt aufzufallen.

# – Einleitung „Internet der Dinge“, Sensoren, Aktoren – 5′

# – Die Arduino Plattform (Hardware, einfache Anwendungen, Sensoren) – 45′

# – Die Raspberry Pi Plattform – 5′ – Arduino’s und Raspberry Pi verbinden – 5′ – Aufbau einer Steuerung anhand zweier konkreter Beispiele (Hausautomation und Modelleisenbahn-Steuerung) – 60′


# - www.arduino.cc

# - Kostengünstig (ab 19$) - Cross-Plattform (Windows, Linux, Mac) -Entwicklungsumgebung

- Schnell erlernbare Programmiersprache,

# basierend auf Wiring (http://wiring.org.co/)

- Gesteuert mittels Codestücken, sogenannten Sketches.

# - Offene und Erweiterbare Software-Libraries auf Basis C++

- Offene und Erweiterbare Hardware. Basierend auf Atmel‘s Mikrocontrollern.

# - Verfügbar in verschiedenen Varianten

Duemilanove (2009), Uno, Mega, Due,

# YÚN

für Shields, I/O Lines; USB (Slave) Anschluss

# Prozessor AtMega328P 8-bit RISC Prozessor inkl. Flash, EEPROM, SRAM

# Systemtaktgenerator

# Stromanschluss 5 – 12 Volt

# Erweiterungsbuchsen

# - Die Arduino-Plattform ist eine aus Soft-und Hardware bestehende Physical-

Computing-Plattform.

# - Physical Computing bedeutet

im weitesten Sinne,

# interaktive, physische Systeme durch die Verwendung von Hardware und Software zu erstellen. Diese Systeme reagieren auf Ereignisse (Sensoren) in der realen, analogen Welt und/oder wirken (Aktoren)

auf sie ein.

## - http://de.wikipedia.org/wiki/Arduino-Plattform

# USB-to-serial driver Chip

# Spannungswandler auf 5 Volt


# - Mittels Erweiterungsboards, sogenannten Shields, kann die Funktionalität des Board

erweitert werden.

# - Diese werden einfach in die Buchsenleiste des Arduino Board gesteckt und mittels

entsprechender Software angesteuert.

# - Es existieren eine Vielzahl von Shields, u.a. für

# – Netzwerkanbindung mittels RJ45 / Ethernet

– Ansteuerung von Motoren (Lokomotiven).

# – Ein Shield zum Abspielen von Sounddateien (u.a. MP3) z.B. Für Bahnhofsdurchsagen – Schalten von 220V Verbrauchern

– IO Expansion Shields für Anschluss von Servo, LED, Rückmelder, I2C, RS 485 etc.

Ethernet-Shield | MotoMama (Motor) Shield | IO Expansion Shield


## Arduino ADK: Steuerung von USB Geräten

## RAMPS: Steuerung von 3D Druckern

## LiliPad: integriert in Kleidung

## NinjaBlocks: Hausautomation


# - https://github.com/mc-b/microSRCP/wiki/Grundkomponenten#wiki-Entwicklungsumgebung


# - https://github.com/mc-b/microSRCP/wiki/Grundkomponenten#wiki-Entwicklungsumgebung

## Port zuweisen: - Windows COM? - Linux/Mac: /dev/ttyUSB0 (2009) /dev/ttyACM0 (Uno)

# MotoMama Shield 2 Motordriver mit je 2A


# - Pin 8 - Input 1: Vorwärts - Pin 9 - Input 2: Rückwärts - Pin 10 - Enable A: Geschwindigkeit - 11 wie 10, 12 wie 8, 13 wie 9

### - (http://de.wikipedia.org/wiki/Vierquadrantensteller) - (http://rn-wissen.de/index.php/Getriebemotoren_Ansteuerung)

# IO Expansion Shield - 4 LED an Pin 4-7 - 1 Servo an Pin 3 - 3 Sensoren an Pin A0-A2


# Seedstudio Side Shield - Vordoppelt die Shield Fläche

# Arduino Duemilanove (2009) - oder Arduino Mega - mit Atmega1280

# Uno machen Probleme mit Ubuntu/Debian


# - Installiert die benötigte Software (Entwicklungsumgebung, Treiber) bzw. startet die VMWare Umgebung

- Schliesst das Arduino Board an den Computer an.

# - Wählt unter Datei-> Beispiele -> 01. Basics den Blink

Sketch aus.

# - Wählt unter Tools -> Board das Board (Arduino 2009 oder Uno) und unter Tool -> Serieller Port den Port

(com? Windows, ansonsten /dev/ttyUSB? Arduino 2009, /dev/ttyACM? Arduino Uno) aus.

# - Ändert ‘int led’ = 13 auf ‘int led = 4’ - Nach Überprüfen und Upload, sollte das Led an Pin 4

Blinken.


ACHTUNG: +5v und GND sind im obiger Zeichnung vertauscht.


# Siehe: http://de.wikipedia.org/wiki/Pulsweitenmodulation

## ACHTUNG: vorher Servo-Hebel ausstecken und richtigen Pin verwenden!


## H-Bridge (L298)

## http://www.rn-wissen.de/index.php/Getriebemotoren_Ansteuerung

# http://arduino.cc/en/Reference/HomePage http://arduino.cc/en/Reference/Libraries

# - Sensoren erlauben es auf externe Meldungen zu reagieren und ermöglichen so automatisierte Abläufe (Pendelzug) - Arduino kann Analoge, Digitale, Serielle (RS-232C) und I2C

Meldungen auswerten.

# - Beispiele für Sensoren sind:

# – Temperator-Sensor – 2/3 Axis Sensor (analog Smartphones), Tilt-Sensor – Licht-Sensor (Infrarot) – Taster, Potentiometer, Push-Button, Reed-Kontakt, Joystick – Hall Sensor (Metall-Detektor)

- Sensoren (Rückmelder) ermöglichen automatischen Betrieb auf der Anlage.

# Sie melden eine bestimmte Position einer Lokomotive und können so z.B. für

die Steuerung einer Pendelzugstrecke eingesetzt werden.

# - Die Steuerung verwendet einfache Reed-Kontakte (Reed vom englischen Röhrchen) welche direkt an das Board (A0-A2) angeschlossen und mittels

Magnet geschaltet werden.

# - Das Übungsmodel besteht aus einer Strecke mit einem Abstellgleis - Drei Sensoren (Rückmelder) ermöglichen einen Pendelzugbetrieb - Mittels einer Weiche mit Servo kann das Abstellgleis angesteuert

werden.

# - Zwei Lichtsignale (mit 2 LED) erlauben visuellen Feedback

# - Die Arduino-Plattform ist eine aus Soft-und Hardware bestehende Physical-Computing-Plattform

# - Wikipedia (http://de.wikipedia.org/wiki/Physical_Computing):

– Physical Computing bedeutet im weitesten Sinne, interaktive, physische Systeme durch die Verwendung von Hardware und Software zu erstellen. Diese Systeme reagieren auf Ereignisse in der realen, analogen Welt und/oder wirken auf sie ein. Obwohl diese Definition auch auf automatische Verkehrskontrollsysteme zutrifft, wird sie in diesem Zusammenhang nicht verwendet. Unter Physical Computing werden Systeme verstanden, die sich mit der Beziehung zwischen dem Menschen und der digitalen Welt befassen. Der Begriff wird meistens für Projekte mit einem künstlerischen oder Designhintergrund oder für Do-it-yourself-Hobbyprojekte verwendet. Dabei werden Sensoren und Mikrocontroller verwendet, um analoge Eingaben Software-Anwendungen verfügbar zu machen und/oder elektromechanische

Geräte, wie Motoren, Servos, Leuchtdioden oder andere Hardware steuern.

# - Einfache Programmierung mittels Sketches und einen Vielzahl von Shield’s

machen die Arduino zu einem universell einsetzbaren I/O Gerät.

# – Einleitung „Internet der Dinge“, Sensoren, Aktoren – 5′

# – Die Arduino Plattform (Hardware, einfache Anwendungen, Sensoren) – 45′

# – Die Raspberry Pi Plattform – 5′ – Arduino’s und Raspberry Pi verbinden – 5′ – Aufbau einer Steuerung anhand zweier konkreter Beispiele (Hausautomation und Modelleisenbahn-Steuerung) – 60′

# - Der Raspberry Pi ist ein kreditkarten-

# grosser Einplatinencomputer - Die Platine enthält das Ein-Chip-System BCM 2835 von Broadcom mit dem 700-MHz-Hauptprozessor ARM1176JZF-S sowie 512 MB Arbeitsspeicher. Das Modell B hat zudem eine Ethernet-Schnittstelle und einen zweiten USB-

Anschluss.
- Linux und andere Betriebssysteme,

# welche die ARM-Architektur

unterstützen, können installiert werden.

# - Eine Festplattenschnittstelle ist nicht vorhanden. Stattdessen können Speicherkarten (SD bzw. MMC) als nichtflüchtiger Speicher oder externe Festplatten und USB-Sticks über den

USB-Port benutzt werden.

# - http://de.wikipedia.org/wiki/Raspberry_Pi

# - Wegen des günstigen Preises und der geringen Leistungsaufnahme des Raspberry Pi ergeben sich abseits der vorgesehenen Nutzung als Schulrechner noch andere Möglichkeiten:

# – Musik-Streaming-Client – Media Center (OpenElec, RaspBMC) – Thin Client oder Server (z.B. als Reverse Proxy Server) – als Steuerungsplatine in einem Quadrocopter – Wetterstation – UKW-Radiosender

– WLAN Access Point (http://www.rpiblog.com/2012/12/turn-raspberry-pi-into-wireless-access.html oder

## https://help.ubuntu.com/community/WifiDocs/WirelessBroadcastSystem)

# – Modelleisenbahn Steuerung (RocRail) – Hausautomation Steuerung (fhem)

# - Die empfohlene Linux-Distribution ist das auf Debian basierende Raspbian, welches auch installiert

ist.

# - Zusätzlich sind folgende Produkte installiert:

– Samba – File/Print Server – Arduino –Entwicklungsumgebung – chromium-browser - Chrome – iw – WLAN Tools – tightvncserver vncviewer – VNC Server und VNC Viewer (Vergleichbar mit Remote Desktop auf Windows) – Fhem – Freundliche Hausautomatisierung und Energie-Messung – RocRail – Modelleisenbahn Steuerung


## Installation in der Linux Shell:

# - sudo apt-get update - sudo apt-get install samba samba-common-bin arduino \ - chromium-browser iw tightvncserver vncviewer

## fhem und RocRail Debian bzw. Raspberry Pi Pakete downloaden und jeweils wie folgt installieren:

# - sudo dpkg –i <paket> - sudo apt-get –f install

# - ssh, putty


# – ssh pi@<ip-adresse> – User: pi, Password: arduino

# - VNCViewer(UltraVNC Viewer)

# – vncviewer – Host: <ip-adresse>:1 – Password: arduino

# - GPIO Schnittstelle (Seriell)

# – Durch Anschluss eines USB Serial Adapters an Pin 4 und 5

- Der Raspberry Pi ist ein kreditkartengrosser Einplatinencomputer.

# - Entwicklung:

# – Ein Prototyp mit einem Atmel-ATmega644-Mikrocontroller wurde im

Jahr 2006 produziert. Die Schaltpläne der Platine wurden veröffentlicht.

# – Die Leistungen des Gerätes überzeugten die Entwickler nicht, durch den zu diesem Zeitpunkt eintretenden Booms von Smartphones kamen geeignete ARM-Prozessoren auf den Markt und man fand mit dem BCM2835 einen billigen Prozessor mit verhältnismäßig hoher Leistung und entwarf für diese

CPU eine neue Mehrlagenplatine.

# – Einleitung „Internet der Dinge“, Sensoren, Aktoren – 5′

# – Die Arduino Plattform (Hardware, einfache Anwendungen, Sensoren) – 45′

# – Die Raspberry Pi Plattform – 5′ – Arduino’s und Raspberry Pi verbinden – 5′ – Aufbau einer Steuerung anhand zweier konkreter Beispiele (Hausautomation und Modelleisenbahn-Steuerung) – 60′

- Das Internet der Dinge (auch englisch Internet of Things) beschreibt,

# dass der (Personal) Computer zunehmend als Gerät verschwinden

und durch „intelligente Gegenstände“ ersetzt wird.

- Der Raspberry Pi ist ein kreditkartengrosser Einplatinencomputer.

# - Die Arduino-Plattform ist eine aus Soft-und Hardware bestehende

Physical-Computing-Plattform (I/O Gerät).

# - Kombiniert man phyische Dinge (Modelleisenbahn, Lampe etc.) mit Raspberry Pi und Arduino’s – entsteht ein Netzwerk von „intelligenten

Gegenständen“ welches mit dem Internet verbunden werden kann.

# - Arduino’s werden an USB

# Schnittstelle vom Raspberry Pi

angeschlossen.

# - Der Raspberry PI bildet die Schnittstelle nach aussen und die Arduino’s übernehmen lokale Steuerungs- (Aktor) und Rückmelde- (Sensor) Aufgaben - Vorteile:

# – Flexibel, Universell – Eine Zentrale Steuerung (Raspberry Pi) – Einen Arduino ist billiger zum Ersetzen als einen Raspbery Pi – USB Kabel und Hub’s sind billig und zuverlässig

- Der Raspberry Pi ist ein kreditkartengrosser Einplatinencomputer.

# - Die Arduino-Plattform ist eine aus Soft-und Hardware bestehende

Physical-Computing-Plattform (I/O Gerät).

- Beide Geräte zusammen ergänzen sich gegenseitig.

# – Einleitung „Internet der Dinge“, Sensoren, Aktoren – 5′

# – Die Arduino Plattform (Hardware, einfache Anwendungen, Sensoren) – 45′

# – Die Raspberry Pi Plattform – 5′ – Arduino’s und Raspberry Pi verbinden – 5′ – Aufbau einer Steuerung anhand zweier konkreter Beispiele (Hausautomation und Modelleisenbahn-Steuerung) – 60′

# - Server welche die Clients überwacht und steuert

# - Protokoll zwischen Client und Server - Clients welche die Befehle

# vom Server entgegennehmen und weiterleiten an - Sensoren und Aktoren

– Readkontakte, LED, Servo’s, Motoren etc.

# - Eingabegeräte wie:

# – PC Programm oder APP’s auf dem Smartphone

# Clients

# Protokoll

# Eingabegeräte

# Sensoren und Aktoren

# - Modelleisenbahn Komponenten

# – Server: RaspberryPi/RocRail – Client: Arduino/microSRCPServer – Protokoll: SRCP – Sensoren und Aktoren = Geräte

– Eingabegeräte: RocView, andRoc,

# iRoc …

# - https://github.com/mc-b/microSRCP/wiki - http://de.wikipedia.org/wiki/Rocrail - http://srcpd.sourceforge.net/

# - Rocrail ist eine freie Software zur Steuerung von digitalen Modelleisenbahnen. Die Züge können manuell, voll-automatisch oder in

einem Mischbetrieb gesteuert werden.

# - Hausautomation Komponenten

# – Server: RaspberryPi/fhem – Client: Arduino/StandardFirmata – Protokoll: Firmata – Sensoren und Aktoren = Arduino Pin’s – Eingabegeräte: Browser, andFhem …

## - http://www.fhemwiki.de/wiki/Arduino - http://de.wikipedia.org/wiki/FHEM - http://firmata.org/wiki/Main_Page

# - FHEM ist ein Perl-basiertes Server-programm für die Hausautomation, der zur automatisierten Bedienung von Aktoren wie zum Beispiel Lichtschaltern oder Heizung sowie der Aufzeichnung von Sensorinformationen wie Raum-

temperatur oder Luftfeuchtigkeit dient.

# - Rocrail ist eine freie Software zur Steuerung von digitalen Modelleisenbahnen. Die Züge können manuell, voll-automatisch oder in einem Mischbetrieb gesteuert

werden.
- Es verwaltet Lokomotiven,

# Sensoren, Signale etc. in

Tabellen.

# - Bietet einen komfortablen Gleisplaneditor - Und bietet Automatische

Abläufe mittels Blöcken,


# Fahrstrassen und Fahrplänen. http://wiki.rocrail.net/doku.php?id=stepbystep-de

# Baut mit Rocrail, Raspberry Pi (alternativ VMWare Umgebung) und Arduino eine

funktionsfähige Modelleisenbahnsteuerung auf.

# - microSRCPServer Sketch in Arduino uploaden - Rocrail und RocView starten - Arduino (mit microSRCPServer Sketch) in RocRail als srcp Zentrale einrichten - 2 Stromkreise (Lokomotiven) anlegen (Stromkreis 1 mit Adresse 1 und Stromkreis 2 mit Adresse 2) - Obiger Gleisplan erstellen

# – 3 Rückmelder mit den Adressen 1 – 3 – 2 Signale mit Adresse 1 und 2, die Led sind an Port 0 und 1 – 1 Weiche (Servo) mit Adresse 3 - Schritt für Schritt Anleitung: http://wiki.rocrail.net/doku.php?id=stepbystep-de

# - ACHTUNG: Servo schaltet langsam. Unter Datei -> RocRail Eigenschaften -> Schaltzeiten (Lichtsignale) erhöhen!

# - Blöcke und Fahrstrassen sind die Grundlage von automatischen Abläufen auf

der Modelleisenbahn.

# - Erweitert den Gleisplan um Blöcke und Fahrstrassen

# - Erstellt zuerst die 3 Blöcke mit den Bezeichnungen Block 1 – 3 und die

Richtungszeiger.

# - Setzt bei Block/Fahrstrassen jeweils den Rückmelder des Blocks als enter2in Aktion - Lasst anschliessend automatisch die Fahrstrassen erstellen mittels dem

Pulldownmenu Datei -> Analysieren -> Analysieren.

# - Werden keine Fehler angezeigt, könnt Ihr Block 1 mit Stromkreis 2 (Lokbelegung setzen) belegen, Fahrstrom und Automatikmodus einschalten und dann auf dem

Block 1 die Lok starten.

# - Siehe auch Schritt für Schritt Anleitung ab Punkt 7.3


# - Erweitert die Steuerung durch weitere Eingabegeräte wie ein

Smartphone.

# – Installiert andRoc o.ä. auf Eurem Smartphone – Startet die App mit folgenden Verbindungseinstellungen:

# - Host: <IP-Adresse des Raspberry Pi> - Port: 8051

# - Firmata ist ein generisches Protokoll

# für die Kommunikation mit Mikrocontrollern und einem Host-

Computer.

# - Firmata Libraries existieren für

verschiedene Sprachen C, Java ..
- Das Ziel von Firmata ist es,

# Menschen die vollständige Kontrolle über die Arduino Plattform vom Host-Computer zu geben. D.h. nicht der Firmata Sketch legt fest welche Geräte vom Arduino angesprochen werden sollen, sondern die Konfiguration auf dem Host (hier

fhem).

# - Das Bild links zeigt das Firmata Testprogramm, wo für jeden Pin

dessen Funktion (Input, Output, Servo etc). festgelegt werden kann.

# - FHEM ist ein Perl-basiertes


# Server-programm für die Hausautomation, der zur automatisierten Bedienung von Aktoren wie zum Beispiel Lichtschaltern oder Heizung sowie der Aufzeichnung von Sensorinformationen wie Raumtemperatur oder

Luftfeuchtigkeit dient.

# - http://fhem.de/fhem_DE.html - http://www.fhemwiki.de/wiki/Arduino

# - Baut mit fhem, Raspberry Pi (Alternativ VMWare Umgebung) und Arduino eine kleine Haussteuerung

auf.

# – Startet den Browser und die

fhem Oberfläche.

# – Wählt Edit Files und fhem.cng – Ergänzt mindestens die nebenstehenden Zeilen (je nach Arduino ist der Serielle Port zu ändern) – Startet fhem neu, falls es nicht selber startet

## sudo service fhem stop sudo service fhem start

# definiere FRM als IO-Device - Baudrate 57600

# Led 4 an Device Arduino1 im Wohnzimmer

attr Led4 room Wohnzimmer | http://www.fhemwiki.de/wiki/Arduino

# Pin A1 und A2 als Input zum ein und

# ausschalten von Led 4

define Input1 FRM_IN 15

attr Input1 room Wohnzimmer

define Input2 FRM_IN 16

attr Input2 room Wohnzimmer

define Input1Notify notify Input1 set Led4 on

define Input2Notify notify Input2 set Led4 off

# Led 4 alle 5 Sekunden ein und ausschalten

define at1 at +*00:00:10 set Led4 on

define at2 at +*00:00:15 set Led4 off

# - Erweitert die Hausautomation um:

# – Reaktion auf externe Ereignisse (Input, Sensor) – automatisierte Abläufe (z.B. LED alle 5 Sekunden ein-/ausschalten)

# - Weitere Ideen:

# – http://www.fhemwiki.de/wiki/Kat egorie:Code_Snippets (http://www.fhemwiki.de/wiki/Kategorie:Code_Snippets)


# - Erweitert die Steuerung durch weitere Eingabegeräte wie ein

Smartphone.

# – Installiert andFhem o.ä. auf Eurem Smartphone – Startet die App mit folgenden Verbindungseinstellungen:

# - URL: <IP-Adresse des Raspberry Pi>:8083/fhem

# - https://github.com/mc-b/microHOME/wiki

# - Kombiniert man phyische Dinge (Modelleisenbahn, Lampe etc.) mit Raspberry Pi und Arduino’s – entsteht ein Netzwerk von „intelligenten

Gegenständen“ welches mit dem Internet verbunden werden kann.


# Sensoren und Aktoren

# - Für Fragen nach dem Kurs sind folgende Links und Foren hilfreich:

# - Arduino

# – http://www.arduino.cc - Hauptseite – http://forum.arduino.cc/ - Forum

– http://playground.arduino.cc// (http://playground.arduino.cc/Deutsch/HomePage)Deutsch/HomePage (http://playground.arduino.cc/Deutsch/HomePage) - Playground

# - fhem

# – http://fhem.de/fhem_DE.html - Hauptseite – http://forum.fhem.de/ - Forum – http://www.fhemwiki.de/wiki/Hauptseite - Wiki

# - microSRCP

# – https://github.com/mc-b/microSRCP/wiki - Wiki – https://github.com/mc-b/microSRCP - Code – http://forum.rocrail.net/viewtopic.php?t=5930&highlight= - Forum RocRail

# - Raspberry Pi

# – http://www.raspberrypi.org/ - Hauptseite – http://www.elinux.org/R-Pi_Hub - Wiki – http://www.raspberrypi.org/phpBB3/ - Forum

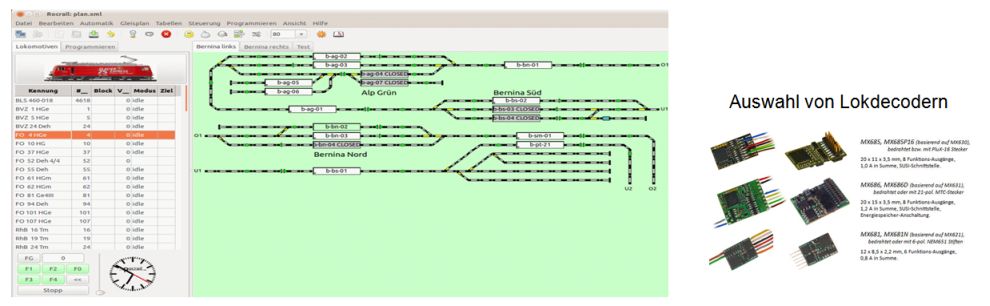
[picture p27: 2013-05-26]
microSRCP/doc/images/MicroSRCP_Digital.jpg

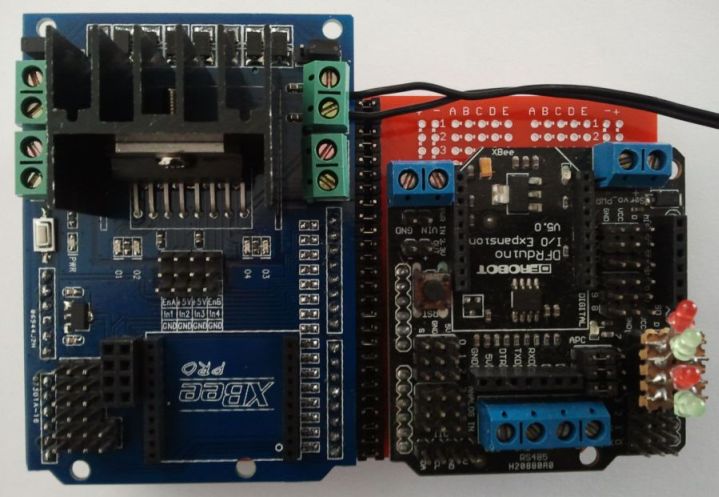
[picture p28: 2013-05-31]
microSRCP/doc/images/MicroSRCP_AnalogeZentrale.jpg

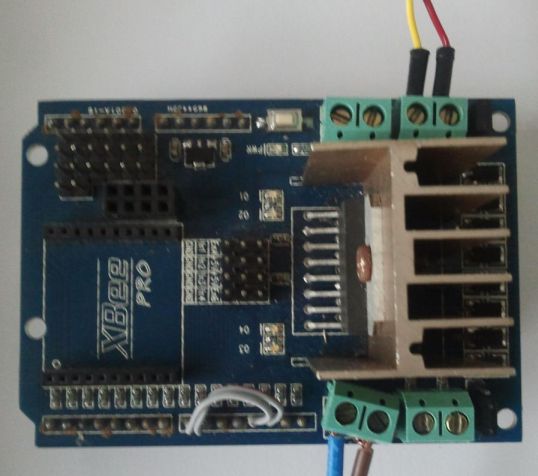
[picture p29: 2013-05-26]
microSRCP/doc/images/microSRCP_MotoMamaGleisanschluss.jpg

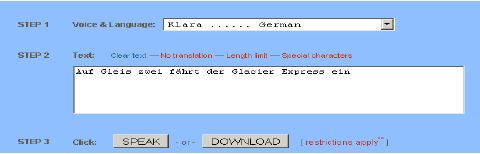
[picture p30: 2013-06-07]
microSRCP/doc/images/MicroSRCP_WaveTool.jpg

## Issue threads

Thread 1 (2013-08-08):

Using Arduino SRCP stack for own project?

dcoredump, 2013-08-08:
Hi Marcel,

can we use your SRCP stack for our own project called "ArduRail"? It is hosted on SF and aims to be a MM central with own (interrupt driven) signal generation. Currently it is a library with an optional P50(X) interface. With your SRCP stack it can be a full SRCP central station.

You can contact me at dcoredump@googlemail.com.

Thanks, Holger

Closed 2022-05-01.

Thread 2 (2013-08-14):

microSRCPODCC  mit Arduino Mega

mc-b, 2013-08-14:
funktioniert die odcc (d.h. die dccout.c mit Interrupt-Routine ) auch auf dem Arduino Mega ? Ich habe an einer Stelle im Code ein entsprechendes #define gefunden woraus ich schliessen würde es geht. (es geht auf jeden Fall zu kompilieren, das habe ich schon ausprobiert.)

Closed 2017-09-25.

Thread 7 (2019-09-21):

Raspian 10 serial

standadHD, 2019-09-21:
Hallo,

Ich habe das Problem ,dass ich rocrail auf einem Raspi 3b betreibe.
Nachdem ich diverse Fehler selbst finden konnte , und mein mega 2560 endlich verbunden ist, erhalte ich im FB Modus unter linux keinerlei Rückmeldungen .

Auf einer Windows Kiste funktioniert es ( Pin 2 an gnd)

standadHD, 2019-09-22:
Auf magische Art läuft es nun ... issue closed

Closed 2019-09-22.

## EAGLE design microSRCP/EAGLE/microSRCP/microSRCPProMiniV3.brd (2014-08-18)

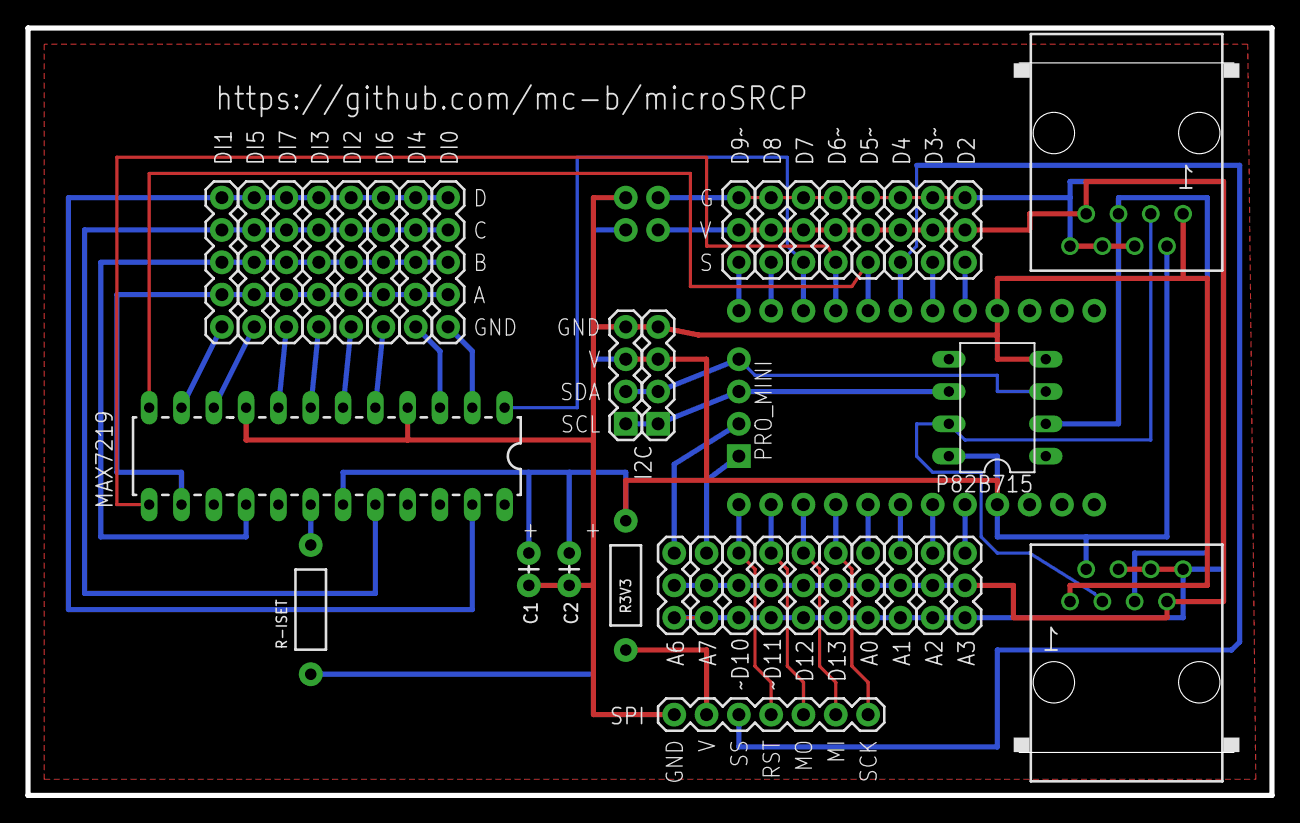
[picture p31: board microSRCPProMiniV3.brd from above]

Board: 2 copper layers, 97.8 x 60.3 mm, 41 parts (0 on the bottom side), 40 nets.

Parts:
A0, A1, A2, A3, A6, A7: 1X03
C1, C2: AXIAL-0.1
D2, D3~, D4, D5~, D6~, D7, D8, D9~, D12, D13: 1X03
DI0, DI1, DI2, DI3, DI4, DI5, DI6, DI7: 1X05
E$1: 1X04_NO_SILK
E$2: 1X04
E$3: R3V3; AXIAL-0.4
E$4, E$5: RJ45-NO-SHIELD
GND: 1X02_NO_SILK
I2C: 1X04
MAX7219: DIL24
P82B715: DIL-08
PRO_MINI: ARDUINO_MINI
R-ISET: AXIAL-0.4
SPI: 1X07
V5: 1X02_NO_SILK
~D10, ~D11: 1X03

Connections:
2-5V: A0.2, A1.2, A2.2, A3.2, A6.2, A7.2, D2.2, D3~.2, D4.2, D5~.2, D6~.2, D7.2, D8.2, D9~.2, D12.2, D13.2, E$4.7, E$5.7, GND.1, ~D10.2, ~D11.2
2-GND: A0.1, A1.1, A2.1, A3.1, A6.1, A7.1, D2.3, D3~.3, D4.3, D5~.3, D6~.3, D7.3, D8.3, D9~.3, D12.1, D13.1, E$4.4, E$4.6, E$4.8, E$5.4, E$5.6, E$5.8, GND.2, ~D10.1, ~D11.1
5V: C1.P$2, C2.P$2, E$2.3, E$3.P$2, E$4.2, E$5.2, I2C.3, MAX7219.19, P82B715.8, PRO_MINI.21, R-ISET.P$1, V5.1
GND: C1.P$1, C2.P$1, E$2.4, E$4.1, E$5.1, I2C.4, MAX7219.4, MAX7219.9, P82B715.4, PRO_MINI.4, SPI.1, V5.2
LSDA: E$4.5, E$5.5, P82B715.2
LSDL: E$4.3, E$5.3, P82B715.7
S$1: E$3.P$1, SPI.2
S$2: D2.1, PRO_MINI.5
S$3: D3~.1, PRO_MINI.6
S$4: D4.1, PRO_MINI.7, SPI.3
S$5: D5~.1, MAX7219.12, PRO_MINI.8
S$6: D6~.1, MAX7219.13, PRO_MINI.9
S$7: D7.1, MAX7219.1, PRO_MINI.10
S$8: D8.1, PRO_MINI.11
S$9: D9~.1, PRO_MINI.12
S$10: PRO_MINI.13, SPI.4, ~D10.3
S$11: PRO_MINI.14, SPI.5, ~D11.3
S$12: D12.3, PRO_MINI.15, SPI.6
S$13: D13.3, PRO_MINI.16, SPI.7
S$14: A0.3, PRO_MINI.17
S$15: A1.3, PRO_MINI.18
S$16: A2.3, PRO_MINI.19
S$17: A3.3, PRO_MINI.20
S$18: DI0.1, MAX7219.2
S$19: DI4.1, MAX7219.3
S$20: DI6.1, MAX7219.5
S$21: DI2.1, MAX7219.6
S$22: DI3.1, MAX7219.7
S$23: DI7.1, MAX7219.8
S$24: DI5.1, MAX7219.10
S$25: DI1.1, MAX7219.11
S$26: DI0.2, DI1.2, DI2.2, DI3.2, DI4.2, DI5.2, DI6.2, DI7.2, MAX7219.14
S$27: MAX7219.18, R-ISET.P$2
S$28: DI0.4, DI1.4, DI2.4, DI3.4, DI4.4, DI5.4, DI6.4, DI7.4, MAX7219.20
S$29: DI0.5, DI1.5, DI2.5, DI3.5, DI4.5, DI5.5, DI6.5, DI7.5, MAX7219.23
S$32: DI0.3, DI1.3, DI2.3, DI3.3, DI4.3, DI5.3, DI6.3, DI7.3, MAX7219.16
S$A6: A6.3, E$1.2
S$A7: A7.3, E$1.1
SDA: E$1.4, E$2.2, I2C.2, P82B715.3
SDL: E$1.3, E$2.1, I2C.1, P82B715.6

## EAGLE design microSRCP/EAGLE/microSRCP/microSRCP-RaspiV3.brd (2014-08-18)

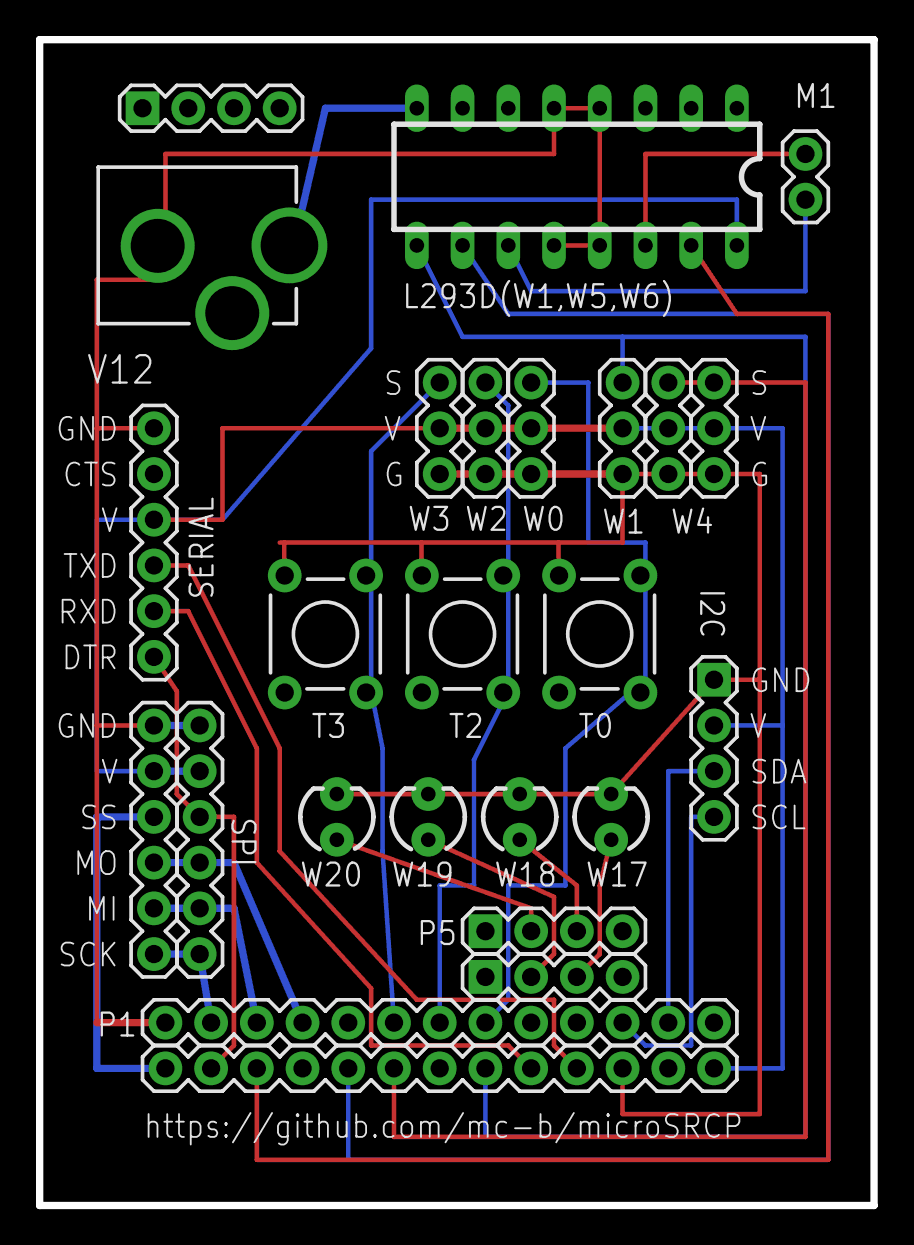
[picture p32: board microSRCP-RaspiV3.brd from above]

Board: 2 copper layers, 46.4 x 64.8 mm, 25 parts (0 on the bottom side), 24 nets.

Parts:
E$1: 1X13
E$2, E$3: 1X04
E$5: 1X06
I2C: 1X04
L293D(W1,W5,W6): DIL16
M1: 1X02
P1: 1X13
P5: 1X04
SERIAL: 1X06
SPI: 1X06
T0, T2, T3: TACTILE-PTH
V12: POWER_JACK_PTH_LOCK
W0, W1, W1N, W2, W3, W4: 1X03
W17, W18, W19, W20: LED3MM

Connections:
5V: E$1.13, E$5.5, I2C.2, L293D(W1,W5,W6).16, SERIAL.4, SPI.2, W0.2, W1.2, W1N.2, W2.2, W3.2, W4.2
GND: E$1.11, E$5.6, I2C.1, L293D(W1,W5,W6).4, L293D(W1,W5,W6).5, L293D(W1,W5,W6).12, L293D(W1,W5,W6).13, P1.1, SERIAL.6, SPI.1, W0.1, W1.1, W1N.1, W2.1, W3.1, W4.1, W17.K, W18.K, W19.K, W20.K
S0: P1.8, W0.3
S1: E$1.8, L293D(W1,W5,W6).9, W4.3
S2: P1.7, W2.3
S3: P1.6, W3.3
S4: E$1.6, W1.3, W1N.3
S5: E$1.5, L293D(W1,W5,W6).10
S6: E$1.3, L293D(W1,W5,W6).15
S$2: E$5.1, P1.2, SPI.6
S$3: E$5.2, P1.3, SPI.5
S$4: E$5.3, P1.4, SPI.4
S$5: E$1.1, SPI.3
S$6: E$1.2, E$5.4, SERIAL.1
S$8: E$3.3, W17.A
S$10: P5.3, W18.A
S$11: E$3.2, W19.A
S$12: P5.2, W20.A
S$13: E$1.9, SERIAL.2
S$14: E$1.10, SERIAL.3
SM1L: L293D(W1,W5,W6).14, M1.1
SM1R: L293D(W1,W5,W6).11, M1.2
SSCL: I2C.4, P1.11
SSDA: I2C.3, P1.12

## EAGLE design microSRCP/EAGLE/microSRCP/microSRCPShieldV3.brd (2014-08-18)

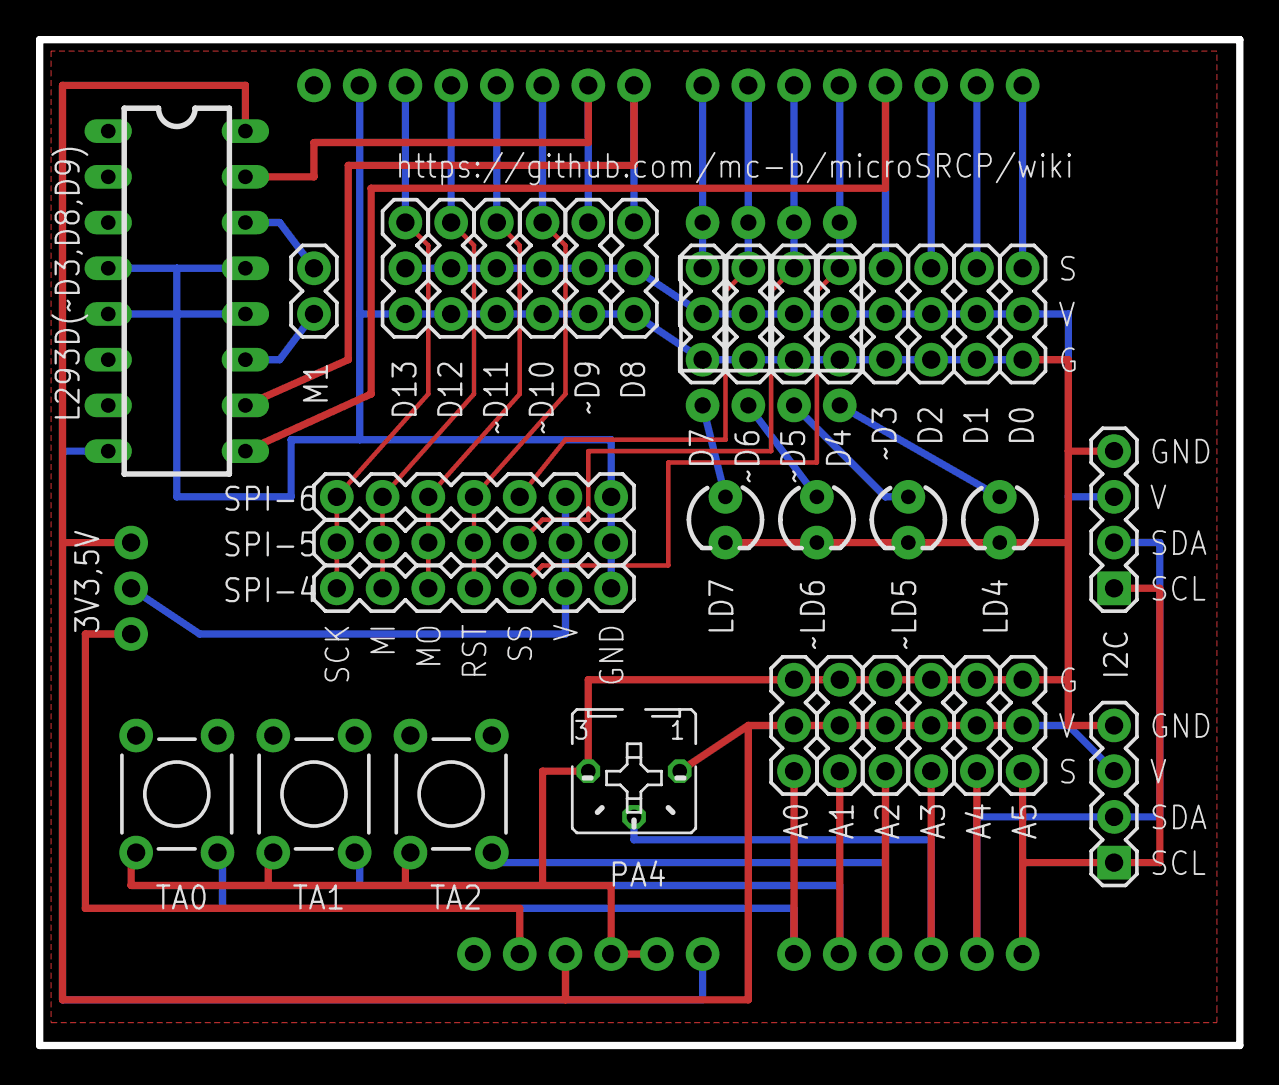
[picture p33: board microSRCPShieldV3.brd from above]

Board: 2 copper layers, 66.7 x 55.9 mm, 41 parts (0 on the bottom side), 31 nets.

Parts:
3V3,5V: 1X03_NO_SILK
A0, A1, A2, A3, A4, A5: 1X03
D0, D1, D2, D4, D7, D8, D12, D13: 1X03
E$1: DUEMILANOVE_SHIELD_NOHOLES_NOLABELS
I2C, I2C-2: 1X04
L293D(~D3,D8,D9): DIL16
LD4, LD7: LED3MM
M1: 1X02
PA4: B25P
R1, R2, R3, R7: AXIAL-0.4
SPI-4, SPI-5, SPI-6: 1X07
TA0, TA1, TA2: TACTILE-PTH
~D3, ~D5, ~D6, ~D9, ~D10, ~D11: 1X03
~LD5, ~LD6: LED3MM

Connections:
GND: A0.3, A1.3, A2.3, A3.3, A4.3, A5.3, D0.3, D1.3, D2.3, D4.3, D7.3, D8.3, D12.3, D13.3, E$1.GND@0, E$1.GND@1, E$1.GND@2, I2C.4, I2C-2.4, L293D(~D3,D8,D9).4, L293D(~D3,D8,D9).5, L293D(~D3,D8,D9).12, L293D(~D3,D8,D9).13, LD4.K, LD7.K, PA4.E, SPI-4.7, SPI-5.7, SPI-6.7, ~D3.3, ~D5.3, ~D6.3, ~D9.3, ~D10.3, ~D11.3, ~LD5.K, ~LD6.K
S0: D0.1, E$1.RX
S1: D1.1, E$1.TX
S2: D2.1, E$1.D2
S3: E$1.D3, L293D(~D3,D8,D9).9, ~D3.1
S3V3: 3V3,5V.1, E$1.3.3V
S5: E$1.D5, R2.P$2, SPI-5.5, ~D5.1
S6: E$1.D6, R1.P$2, SPI-6.5, ~D6.1
S7: D7.1, E$1.D7, R7.P$2
S8: D8.1, E$1.D8, L293D(~D3,D8,D9).10
S10: E$1.D10, SPI-4.4, SPI-5.4, SPI-6.4, ~D10.1
S11: E$1.D11, SPI-4.3, SPI-5.3, SPI-6.3, ~D11.1
S12: D12.1, E$1.D12, SPI-4.2, SPI-5.2, SPI-6.2
S13: D13.1, E$1.D13, SPI-4.1, SPI-5.1, SPI-6.1
S$1: R2.P$1, ~LD5.A
S$2: 3V3,5V.2, SPI-4.6, SPI-5.6, SPI-6.6
S$3: E$1.D9, L293D(~D3,D8,D9).15, ~D9.1
S$4: D4.1, E$1.D4, R3.P$2, SPI-4.5
S$9: LD4.A, R3.P$1
S$11: R1.P$1, ~LD6.A
S$12: LD7.A, R7.P$1
SA0: A0.1, E$1.A0
SA1: A1.1, E$1.A1
SA2: A2.1, E$1.A2
SA3: A3.1, E$1.A3, PA4.S
SA4: A4.1, E$1.A4, I2C.2, I2C-2.2
SA5: A5.1, E$1.A5, I2C.1, I2C-2.1
SM1-L: L293D(~D3,D8,D9).14, M1.2
SM1R: L293D(~D3,D8,D9).11, M1.1
SVIN: E$1.VIN, L293D(~D3,D8,D9).8
V5O: 3V3,5V.3, A0.2, A1.2, A2.2, A3.2, A4.2, A5.2, D0.2, D1.2, D2.2, D4.2, D7.2, D8.2, D12.2, D13.2, E$1.5V, I2C.3, I2C-2.3, L293D(~D3,D8,D9).16, PA4.A, ~D3.2, ~D5.2, ~D6.2, ~D9.2, ~D10.2, ~D11.2

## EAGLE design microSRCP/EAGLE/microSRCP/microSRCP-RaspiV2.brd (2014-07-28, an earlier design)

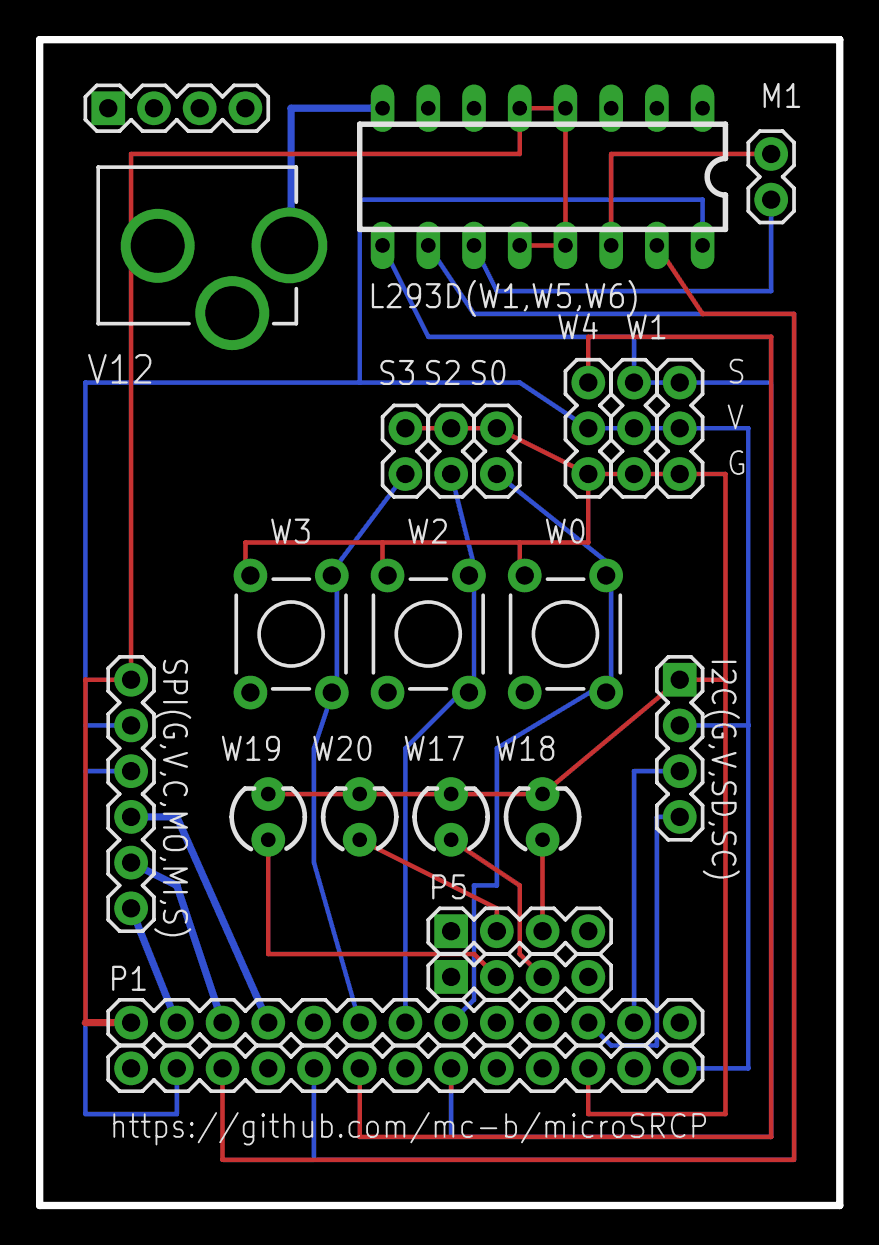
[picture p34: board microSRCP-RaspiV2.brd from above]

Board: 2 copper layers, 44.4 x 64.8 mm, 23 parts (0 on the bottom side), 22 nets.

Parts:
E$1: 1X13
E$2, E$3: 1X04
I2C(G,V,SD,SC): 1X04
L293D(W1,W5,W6): DIL16
M1: 1X02
P1: 1X13
P5: 1X04
S0, S2, S3: 1X02
SPI(G,V,C,MO,MI,S): 1X06
V12: POWER_JACK_PTH_LOCK
W0, W2, W3: TACTILE-PTH
W1, W1N, W4: 1X03
W17, W18, W19, W20: LED3MM

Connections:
5V: E$1.13, I2C(G,V,SD,SC).2, L293D(W1,W5,W6).16, SPI(G,V,C,MO,MI,S).2, W1.2, W1N.2, W4.2
GND: E$1.11, I2C(G,V,SD,SC).1, S0.2, S2.2, S3.2, W1.1, W1N.1, W4.1, W17.K, W18.K, W19.K, W20.K
GND2: L293D(W1,W5,W6).4, L293D(W1,W5,W6).5, L293D(W1,W5,W6).12, L293D(W1,W5,W6).13, P1.1, SPI(G,V,C,MO,MI,S).1
S0: P1.8, S0.1
S1: E$1.8, L293D(W1,W5,W6).9, W1.3, W1N.3
S2: P1.7, S2.1
S3: P1.6, S3.1
S4: E$1.6, W4.3
S5: E$1.5, L293D(W1,W5,W6).10
S6: E$1.3, L293D(W1,W5,W6).15
S17: P5.3, W18.A
S18: E$3.3, W17.A
S19: P5.2, W20.A
S20: E$3.2, W19.A
SCE0: E$1.2, SPI(G,V,C,MO,MI,S).3
SM1L: L293D(W1,W5,W6).14, M1.1
SM1R: L293D(W1,W5,W6).11, M1.2
SMISO: P1.3, SPI(G,V,C,MO,MI,S).5
SMOSI: P1.4, SPI(G,V,C,MO,MI,S).4
SSCL: I2C(G,V,SD,SC).4, P1.11
SSCLK: P1.2, SPI(G,V,C,MO,MI,S).6
SSDA: I2C(G,V,SD,SC).3, P1.12

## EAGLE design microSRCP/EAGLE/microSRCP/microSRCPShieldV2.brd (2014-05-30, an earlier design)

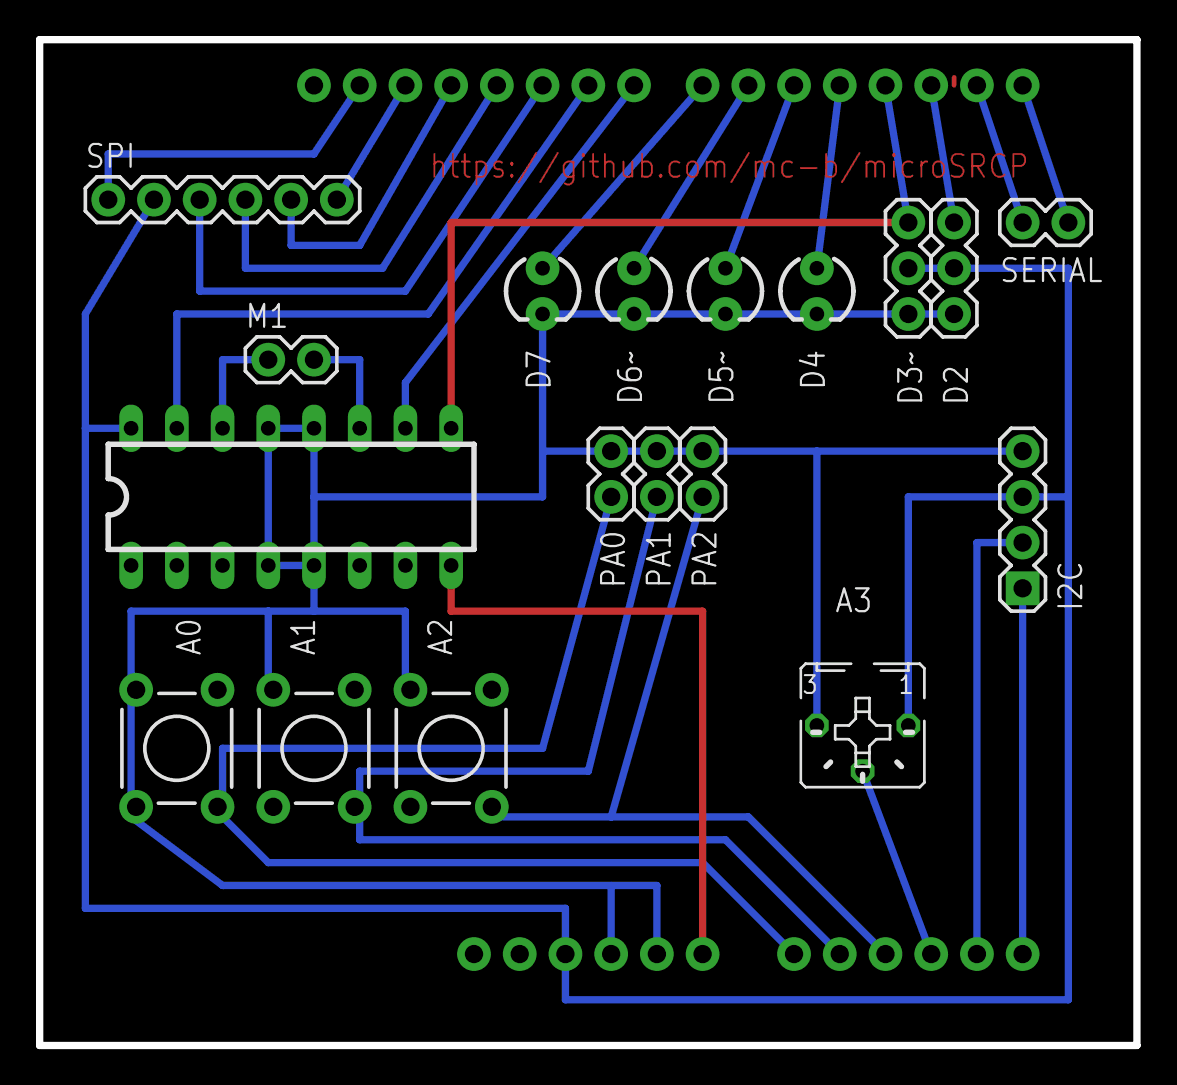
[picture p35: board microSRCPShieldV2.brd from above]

Board: 2 copper layers, 61.0 x 55.9 mm, 19 parts (0 on the bottom side), 25 nets.

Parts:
1: L293D; DIL16
90: DUEMILANOVE_SHIELD_NOHOLES_NOLABELS
A0, A1, A2: TACTILE-PTH
A3: B25P
D2, D3~: 1X03
D4, D5~, D6~, D7: LED3MM
I2C: 1X04
M1: 1X02
PA0, PA1, PA2: 1X02
SERIAL: 1X02
SPI: 1X06

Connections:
5V: 1.16, 90.5V, A3.A, D2.2, D3~.2, I2C.3, SPI.2
GND: 1.4, 1.5, 1.12, 1.13, 90.GND@0, 90.GND@1, A3.E, D2.1, D3~.1, D4.K, D5~.K, D6~.K, D7.K, I2C.4, PA0.2, PA1.2, PA2.2
GND2: 90.GND@2, SPI.1
S$1: 90.D10, SPI.3
S$2: 90.A5, I2C.1
S$3: 1.15, 90.D9
S$4: 90.D13, SPI.6
S$5: 90.D7, D7.A
S$6: 90.D6, D6~.A
S$7: 90.D5, D5~.A
S$8: 90.D4, D4.A
S$9: 1.9, 90.D3, D3~.3
S$10: 90.D2, D2.3
S$11: 90.D12, SPI.5
S$12: 90.TX, SERIAL.1
S$13: 90.RX, SERIAL.2
S$14: 90.D11, SPI.4
S$16: 90.A4, I2C.2
S$17: 90.A0, PA0.1
S$19: 90.A2, PA2.1
S$21: 90.A3, A3.S
S$22: 1.11, M1.2
S$24: 1.14, M1.1
S$25: 1.10, 90.D8
VIN: 1.8, 90.VIN

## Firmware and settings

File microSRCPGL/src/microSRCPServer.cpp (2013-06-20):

/*
	microSRCPServer - Arduino Standardboard fungiert als Zentrale
	fuer eine Modelleisenbahn wird mittels USB Kabel an den PC angeschlossen.

	Zusaetzlich wird einen Modelleisenbahnsteuerungssoftware z.B.
	RocRail, benoetigt, welche das SRCP Protokoll beherscht.

	Fuer benoetigte Shields und Details siehe:
	- https://github.com/mc-b/microSRCP/wiki/Steuerungkonfiguration
	- https://github.com/mc-b/microSRCP/wiki

	Copyright (c) 2010 - 2013 Marcel Bernet.  All right reserved.

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
	You should have received a copy of the GNU General Public License
	along with this program; if not, write to the Free Software
	Foundation, Inc., 51 Franklin Street, Fifth Floor, Boston, MA  02110-1301, USA.
 */

//////////////////////////////////////////////////////////////////////////////////////////
// Konfiguration Protokoll
#define SRCP_ETHERNET	100
#define SRCP_SERIAL		101
#define SRCP_I2C		102

#define SRCP_PROTOCOL	SRCP_SERIAL

#define SENSOR_POLLING	500			// Intervall in welcher Sensor Aenderungen an die Zentrale gemeldet werden

//////////////////////////////////////////////////////////////////////////////////////////
// Konfiguration Board
#define BOARD_STANDARD		200
#define BOARD_I2C_MASTER 	201
#define BOARD_MINIMAL  		202		// Minialer Board Aufbau, nur Resonator, 10K, Atmega328P
#define BOARD_FB			203		// Beispiel ATmega328P: nur Sensoren (Feedback)
#define BOARD_GA			204		// Beispiel ATmega328P: nur Generic Accessoires - Geraete
#define BOARD_GL			205		// Beispiel ATmega328P: nur Motorenansteuerung

#define BOARD 	BOARD_STANDARD

//////////////////////////////////////////////////////////////////////////////////////////
// Konfiguration I2C
#define I2C_ADDR		0	// Eigene I2C Adresse - muss pro I2C Board angepasst werden! - Master = 0
#define I2C_OFFSET		16	// Offset, d.h. wieviele Adressen pro Board reserviert werden
#define I2C_ENABLED		1
#define I2C_MAX_SLAVES	10	// Maximale Anzahl I2C Slave Boards am Master
#define ADDR(x)			((I2C_ADDR * I2C_OFFSET) + x)	// Berechnung effektive Adresse

#include <Arduino.h>
#include <HardwareSerial.h>
#include <log/Logger.h>
#include <srcp/SRCPCommand.h>
#include <srcp/SRCPDeviceManager.h>
#if	( SRCP_PROTOCOL == SRCP_SERIAL )
#include <srcp/SRCPServerSerial.h>
#endif
#if ( SRCP_PROTOCOL == SRCP_ETHERNET )
#include <lan/EthernetSRCPServer.h>
#endif
#include <i2c/I2CDeviceManager.h>
#include <dev/GASignal.h>
#include <dev/GASlowServo.h>
#include <dev/GABlinkLed2.h>
#include <dev/GLMotoMamaAnalog.h>
#include <dev/FBSwitchSensor.h>

#if	( SRCP_PROTOCOL == SRCP_SERIAL )
// SRCP I/O Server
srcp::SRCPServerSerial server;
#elif ( SRCP_PROTOCOL == SRCP_ETHERNET )
lan::EthernetSRCPServer server;
// Enter a MAC address and IP address for your controller below.
// The IP address will be dependent on your local network:
byte mac[] = { 0xDE, 0xAD, 0xBE, 0xEF, 0xFE, 0xED };
IPAddress ip( 192, 168, 178, 241 );
#elif  ( SRCP_PROTOCOL == SRCP_I2C )
// SRCP I2C - Slave
i2c::I2CServer server = WireServer;
#else
#error "kein Prokotoll definiert"
#endif

/**
 * Initialisierung - Protokoll, Geraete etc.
 */
void setup()
{
	BEGIN( 9600 );
	INFO( "Logger ready" );

#if	( SRCP_PROTOCOL != SRCP_ETHERNET )											// Board mit Ethernet Shield hat keine Geraete um Konflikte mit Shield zu vermeiden!
#if	( BOARD == BOARD_STANDARD )
	// Geraete initialisieren, je nach Board und Verwendung
	DeviceManager.addAccessoire( new dev::GASignal( ADDR(1), 4, 5 ) ); 			// 2 Signale mit 2 LED an Ports 4 - 7.
	DeviceManager.addAccessoire( new dev::GASignal( ADDR(2), 6, 7 ) );
	DeviceManager.addAccessoire( new dev::GASlowServo( ADDR(3), 2, 60, 90 ) );  	// Servo mit Addr 3 an Pin 2, min. Stellung 60, max. Stellung 90 von 180
	DeviceManager.addAccessoire( new dev::GASlowServo( ADDR(4), 3, 60, 90 ) );			// und Weiterschalten um 1ne Position alle 5 Millisekunden
	DeviceManager.addFeedback( new dev::FBSwitchSensor( ADDR(1), A0, A3 ) ); 	// Sensoren, jeweils in Gruppen von 8 (auch wenn nicht 8 Pins belegt). A4+A5 = I2C Bus
#if ( __AVR_ATmega1280__ || __AVR_ATmega2560__ )
	DeviceManager.addFeedback( new dev::FBSwitchSensor( ADDR(9), A8, A15 ) ); 	// Sensoren, Mega 8 zusaetzlich
	DeviceManager.addLoco( new dev::GLMotoMamaAnalog( ADDR(1), 10,  8,  9 ) ); 	// Moto Mama Shield, Pin 10 Geschwindigkeit, 8 Vor-, 9 Rueckwaerts - nur Mega
#endif
	DeviceManager.addLoco( new dev::GLMotoMamaAnalog( ADDR(2), 11, 12, 13 ) );
#elif	( BOARD == BOARD_MINIMAL )
	DeviceManager.addAccessoire( new dev::GASlowServo( ADDR(1), 9, 60, 90 ) ); 		// 6 x Servo's an Pins 0 - 4 und 9
	DeviceManager.addAccessoire( new dev::GASlowServo( ADDR(2), 0, 60, 90 ) );
	DeviceManager.addAccessoire( new dev::GASlowServo( ADDR(3), 1, 60, 90 ) );
	DeviceManager.addAccessoire( new dev::GASlowServo( ADDR(4), 2, 60, 90 ) );
	DeviceManager.addAccessoire( new dev::GASlowServo( ADDR(5), 3, 60, 90 ) );
	DeviceManager.addAccessoire( new dev::GASlowServo( ADDR(6), 4, 60, 90 ) );
	DeviceManager.addAccessoire( new dev::GASignal( ADDR(7), 5, 6 ) ); 			// 2 x Signal mit 2 LED an Pins 5 - 8
	DeviceManager.addAccessoire( new dev::GASignal( ADDR(8), 7, 8 ) );
	DeviceManager.addFeedback( new dev::FBSwitchSensor( ADDR(1), 10, 17 ) );	// 1 x Sensorblock mit 8 x Sensor an Pin D10 - D13 und C0 - C3
#elif	( BOARD == BOARD_FB && __AVR_ATmega328P__ )
	DeviceManager.addFeedback( new dev::FBSwitchSensor( ADDR(1),  2,  9 ) );	// 1 x Sensorblock mit 8 x Sensor an Pin D2 - D9
	DeviceManager.addFeedback( new dev::FBSwitchSensor( ADDR(9), 10, 17 ) );	// 1 x Sensorblock mit 7 x Sensor an Pin D10 - A4 (A0 = 14), Pin 13 ohne Funktion wegen LED
#elif	( BOARD == BOARD_GA && __AVR_ATmega328P__ )
	DeviceManager.addAccessoire( new dev::GASlowServo( ADDR(1),  2, 60, 90 ) );	// 8 x Servo (max. fuer ATmega328P)
	DeviceManager.addAccessoire( new dev::GASlowServo( ADDR(2),  3, 60, 90 ) );
	DeviceManager.addAccessoire( new dev::GASlowServo( ADDR(3),  8, 60, 90 ) ); // abgestimmt auf DF Robot I/ Expansion Shield, darum die Luecke
	DeviceManager.addAccessoire( new dev::GASlowServo( ADDR(4),  9, 60, 90 ) );
	DeviceManager.addAccessoire( new dev::GASlowServo( ADDR(5), 10, 60, 90 ) );
	DeviceManager.addAccessoire( new dev::GASlowServo( ADDR(6), 11, 60, 90 ) );
	DeviceManager.addAccessoire( new dev::GASlowServo( ADDR(7), 12, 60, 90 ) );
	DeviceManager.addAccessoire( new dev::GASlowServo( ADDR(8), 13, 60, 90 ) );
	DeviceManager.addAccessoire( new dev::GASignal( ADDR(9), 4, 5 ) ); 			// 4 x Lichtsignal
	DeviceManager.addAccessoire( new dev::GASignal( ADDR(10), 6, 7 ) );
	DeviceManager.addAccessoire( new dev::GASignal( ADDR(11), A0, A1 ) );
	DeviceManager.addAccessoire( new dev::GASignal( ADDR(12), A2, A3 ) );
#elif	( BOARD == BOARD_GL && __AVR_ATmega328P__ )
	DeviceManager.addLoco( new dev::GLMotoMamaAnalog( ADDR(1), 10,  8,  9 ) ); 	// Moto Mama Shield, Pin 10 Geschwindigkeit, 8 Vor-, 9 Rueckwaerts
	DeviceManager.addLoco( new dev::GLMotoMamaAnalog( ADDR(2), 11, 12, 13 ) );
#endif
#endif

#if	( SRCP_PROTOCOL != SRCP_I2C && I2C_ENABLED )
	// initialize I2C - Master braucht keine Adresse
	i2c::I2CDeviceManager::begin( I2C_MAX_SLAVES );	 // weitere Boards am I2C Bus, beginnend mit Adressen (I2C_ADDR * I2C_OFFSET) + x).
#endif


	INFO_DEVICES();									// Ausgabe der installierten Geraete

	// SRCP Kommunikation oeffnen
#if	( SRCP_PROTOCOL == SRCP_SERIAL )
	server.begin( 115200 );
#elif ( SRCP_PROTOCOL == SRCP_ETHERNET )
	server.begin( mac, ip, 4303 );
#elif  ( SRCP_PROTOCOL == SRCP_I2C )
	// initialize I2C - Slave
	server.begin( I2C_ADDR );
#endif

	INFO ( "Server listen" );
}

/**
 * Endlosloop
 */
void loop()
{
	// Host Meldungen verarbeiten
	server.dispatch( SENSOR_POLLING );

	// Refresh der Sensoren bzw. Abfragen ob Aenderungen stattgefunden haben
	DeviceManager.refresh();
}

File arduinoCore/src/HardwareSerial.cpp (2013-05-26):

/*
  HardwareSerial.cpp - Hardware serial library for Wiring
  Copyright (c) 2006 Nicholas Zambetti.  All right reserved.

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
  Modified 23 November 2006 by David A. Mellis
  Modified 28 September 2010 by Mark Sproul
  Modified 14 August 2012 by Alarus
*/

#include <stdlib.h>
#include <stdio.h>
#include <string.h>
#include <inttypes.h>
#include "Arduino.h"
#include "wiring_private.h"

// this next line disables the entire HardwareSerial.cpp, 
// this is so I can support Attiny series and any other chip without a uart
#if defined(UBRRH) || defined(UBRR0H) || defined(UBRR1H) || defined(UBRR2H) || defined(UBRR3H)

#include "HardwareSerial.h"

/*
 * on ATmega8, the uart and its bits are not numbered, so there is no "TXC0"
 * definition.
 */
#if !defined(TXC0)
#if defined(TXC)
#define TXC0 TXC
#elif defined(TXC1)
// Some devices have uart1 but no uart0
#define TXC0 TXC1
#else
#error TXC0 not definable in HardwareSerial.h
#endif
#endif

// Define constants and variables for buffering incoming serial data.  We're
// using a ring buffer (I think), in which head is the index of the location
// to which to write the next incoming character and tail is the index of the
// location from which to read.
#if (RAMEND < 1000)
  #define SERIAL_BUFFER_SIZE 16
#else
  #define SERIAL_BUFFER_SIZE 64
#endif

struct ring_buffer
{
  unsigned char buffer[SERIAL_BUFFER_SIZE];
  volatile unsigned int head;
  volatile unsigned int tail;
};

#if defined(USBCON)
  ring_buffer rx_buffer = { { 0 }, 0, 0};
  ring_buffer tx_buffer = { { 0 }, 0, 0};
#endif
#if defined(UBRRH) || defined(UBRR0H)
  ring_buffer rx_buffer  =  { { 0 }, 0, 0 };
  ring_buffer tx_buffer  =  { { 0 }, 0, 0 };
#endif
#if defined(UBRR1H)
  ring_buffer rx_buffer1  =  { { 0 }, 0, 0 };
  ring_buffer tx_buffer1  =  { { 0 }, 0, 0 };
#endif
#if defined(UBRR2H)
  ring_buffer rx_buffer2  =  { { 0 }, 0, 0 };
  ring_buffer tx_buffer2  =  { { 0 }, 0, 0 };
#endif
#if defined(UBRR3H)
  ring_buffer rx_buffer3  =  { { 0 }, 0, 0 };
  ring_buffer tx_buffer3  =  { { 0 }, 0, 0 };
#endif

inline void store_char(unsigned char c, ring_buffer *buffer)
{
  int i = (unsigned int)(buffer->head + 1) % SERIAL_BUFFER_SIZE;

  // if we should be storing the received character into the location
  // just before the tail (meaning that the head would advance to the
  // current location of the tail), we're about to overflow the buffer
  // and so we don't write the character or advance the head.
  if (i != buffer->tail) {
    buffer->buffer[buffer->head] = c;
    buffer->head = i;
  }
}

#if !defined(USART0_RX_vect) && defined(USART1_RX_vect)
// do nothing - on the 32u4 the first USART is USART1
#else
#if !defined(USART_RX_vect) && !defined(SIG_USART0_RECV) && \
    !defined(SIG_UART0_RECV) && !defined(USART0_RX_vect) && \
	!defined(SIG_UART_RECV)
  #error "Don't know what the Data Received vector is called for the first UART"
#else
  void serialEvent() __attribute__((weak));
  void serialEvent() {}
  #define serialEvent_implemented
#if defined(USART_RX_vect)
  SIGNAL(USART_RX_vect)
#elif defined(SIG_USART0_RECV)
  SIGNAL(SIG_USART0_RECV)
#elif defined(SIG_UART0_RECV)
  SIGNAL(SIG_UART0_RECV)
#elif defined(USART0_RX_vect)
  SIGNAL(USART0_RX_vect)
#elif defined(SIG_UART_RECV)
  SIGNAL(SIG_UART_RECV)
#endif
  {
  #if defined(UDR0)
    if (bit_is_clear(UCSR0A, UPE0)) {
      unsigned char c = UDR0;
      store_char(c, &rx_buffer);
    } else {
      unsigned char c = UDR0;
    };
  #elif defined(UDR)
    if (bit_is_clear(UCSRA, PE)) {
      unsigned char c = UDR;
      store_char(c, &rx_buffer);
    } else {
      unsigned char c = UDR;
    };
  #else
    #error UDR not defined
  #endif
  }
#endif
#endif

#if defined(USART1_RX_vect)
  void serialEvent1() __attribute__((weak));
  void serialEvent1() {}
  #define serialEvent1_implemented
  SIGNAL(USART1_RX_vect)
  {
    if (bit_is_clear(UCSR1A, UPE1)) {
      unsigned char c = UDR1;
      store_char(c, &rx_buffer1);
    } else {
      unsigned char c = UDR1;
    };
  }
#elif defined(SIG_USART1_RECV)
  #error SIG_USART1_RECV
#endif

#if defined(USART2_RX_vect) && defined(UDR2)
  void serialEvent2() __attribute__((weak));
  void serialEvent2() {}
  #define serialEvent2_implemented
  SIGNAL(USART2_RX_vect)
  {
    if (bit_is_clear(UCSR2A, UPE2)) {
      unsigned char c = UDR2;
      store_char(c, &rx_buffer2);
    } else {
      unsigned char c = UDR2;
    };
  }
#elif defined(SIG_USART2_RECV)
  #error SIG_USART2_RECV
#endif

#if defined(USART3_RX_vect) && defined(UDR3)
  void serialEvent3() __attribute__((weak));
  void serialEvent3() {}
  #define serialEvent3_implemented
  SIGNAL(USART3_RX_vect)
  {
    if (bit_is_clear(UCSR3A, UPE3)) {
      unsigned char c = UDR3;
      store_char(c, &rx_buffer3);
    } else {
      unsigned char c = UDR3;
    };
  }
#elif defined(SIG_USART3_RECV)
  #error SIG_USART3_RECV
#endif
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

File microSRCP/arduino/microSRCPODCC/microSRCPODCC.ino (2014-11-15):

/*
	microSRCPODCC - DCC Zentrale basierend auf den Sourcen von
	http://www.opendcc.de.

	Der Code wurde ermoeglicht durch das OpenDCC Projekt und
	die Zurverfuegungstellung der Sourcen von Wolfgang Kufer.
	Besten Dank!

	Fuer benoetigte Shields und Details siehe: 
	- https://github.com/mc-b/microSRCP/wiki/Steuerungdigital
	- https://github.com/mc-b/microSRCP/wiki

	Copyright (c) 2010 - 2013 Marcel Bernet.  All right reserved.

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
	You should have received a copy of the GNU General Public License
	along with this program; if not, write to the Free Software
	Foundation, Inc., 51 Franklin Street, Fifth Floor, Boston, MA  02110-1301, USA.
 */
#include <Arduino.h>
#include <HardwareSerial.h>
#include <Streaming.h>

extern "C"
{
#include <stdlib.h>
#include <inttypes.h>
#include <avr/io.h>
#include <avr/interrupt.h>
#include <avr/pgmspace.h>
#include <avr/eeprom.h>
#include <string.h>

#include "config.h"                // general structures and definitions - make your changes here
#include "parser.h"
#include "dccout.h"                // make dcc
#include "organizer.h"             // manage commands
}

#include <SRCPCommand.h>
#include <SRCPDevice.h>
#include <SRCPDeviceManager.h>
#include <SRCPFeedback.h>
#include <SRCPGenericAccessoire.h>
#include <SRCPGenericLoco.h>
#include <SRCPMessages.h>
#include <SRCPParser.h>
#include <SRCPServerSerial.h>
#include <SRCPSession.h>

#include <Wire.h>
#include <I2CDeviceManager.h>
#include <I2CFBProxy.h>
#include <I2CGAProxy.h>
#include <I2CGLProxy.h>
#include <I2CServer.h>

#include <GAOpenDCC.h>
#include <GLOpenDCC.h>

//////////////////////////////////////////////////////////////////////////////////////////
// Konfiguration Protokoll
#define SRCP_SERIAL		101
#define SRCP_I2C		102
#define SRCP_PROTOCOL	SRCP_SERIAL

#if	( SRCP_PROTOCOL == SRCP_SERIAL )
// SRCP I/O Server
srcp::SRCPServerSerial server;
#elif  ( SRCP_PROTOCOL == SRCP_I2C )
// SRCP I2C - Slave
i2c::I2CServer server = WireServer;
#else
#error "kein Prokotoll definiert"
#endif

//////////////////////////////////////////////////////////////////////////////////////////
// Konfiguration I2C
#define I2C_ADDR		7	// Eigene I2C Adresse - muss pro I2C Board angepasst werden! - Master = 0

// DCC Status
t_opendcc_state opendcc_state; 

/**
 * Initialisierung - Protokoll, Geraete etc.
 */
void setup()
{
	////////////////////////////////////////////////////////////////////////////////////
	// DCC Initialisieren
	init_main();
	init_dccout(); // timing engine for dcc

	init_organizer(); // engine for command repetition, memory of loco speeds and types
	opendcc_state = RUN_OKAY;

#if (__AVR_ATmega328P__)	// Arduino UNO - DCC Signal an Pin 9 + 10, Enable 11 + 12
	// Port A Enable an L298N - MotoMama, DCC Signal an Input 1 + 2
	pinMode( 11, OUTPUT);
	digitalWrite( 11, HIGH );
	// Port B Enable an L298N - MotoMama, DCC Signal an Input 3 + 4
	pinMode( 12, OUTPUT);
	digitalWrite( 12, HIGH );
#elif (__AVR_ATmega1280__ || __AVR_ATmega2560__) // Arduino Mega - DCC Signal an Pin 11 + 12, Enable 9 + 10
	// Port A Enable an L298N - MotoMama, DCC Signal an Input 1 + 2
	pinMode( 9, OUTPUT);
	digitalWrite( 9, HIGH );
	// Port B Enable an L298N - MotoMama, DCC Signal an Input 3 + 4
	pinMode( 10, OUTPUT);
	digitalWrite( 10, HIGH );	
#endif
	
	///////////////////////////////////////////////////////////////////////////////////////////////////////////////////
	// Definition DCC Geraete
	DeviceManager.addAccessoire( new odcc::GAOpenDCC( 1, 2048 ) ); // Weichen, Signale Adressen 1 - 2048 abhandeln
	DeviceManager.addLoco( new odcc::GLOpenDCC( 1, 4096 ) ); // Loks mit Adresessen 1 - 4096 abhandeln

	// SRCP Kommunikation oeffnen
#if	( SRCP_PROTOCOL == SRCP_SERIAL )
	server.begin( 115200 );
#elif  ( SRCP_PROTOCOL == SRCP_I2C )
	// initialize I2C - Slave
	server.begin( I2C_ADDR );
#endif
}

/**
 * Endlosloop
 */
void loop()
{
	// Host Meldungen verarbeiten
	server.dispatch();

	// Refresh der Sensoren bzw. Abfragen ob Aenderungen stattgefunden haben
	DeviceManager.refresh();

	run_organizer(); // run command organizer, depending on state,
	delay( 10 );
}

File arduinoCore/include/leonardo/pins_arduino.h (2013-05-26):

/*
  pins_arduino.h - Pin definition functions for Arduino
  Part of Arduino - http://www.arduino.cc/

  Copyright (c) 2007 David A. Mellis

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
  $Id: pins_arduino.h,v 1.1 2013-02-28 09:47:07 mbern Exp $
*/

#ifndef Pins_Arduino_h
#define Pins_Arduino_h

#include <avr/pgmspace.h>

// Workaround for wrong definitions in "iom32u4.h".
// This should be fixed in the AVR toolchain.
#undef UHCON
#undef UHINT
#undef UHIEN
#undef UHADDR
#undef UHFNUM
#undef UHFNUML
#undef UHFNUMH
#undef UHFLEN
#undef UPINRQX
#undef UPINTX
#undef UPNUM
#undef UPRST
#undef UPCONX
#undef UPCFG0X
#undef UPCFG1X
#undef UPSTAX
#undef UPCFG2X
#undef UPIENX
#undef UPDATX
#undef TCCR2A
#undef WGM20
#undef WGM21
#undef COM2B0
#undef COM2B1
#undef COM2A0
#undef COM2A1
#undef TCCR2B
#undef CS20
#undef CS21
#undef CS22
#undef WGM22
#undef FOC2B
#undef FOC2A
#undef TCNT2
#undef TCNT2_0
#undef TCNT2_1
#undef TCNT2_2
#undef TCNT2_3
#undef TCNT2_4
#undef TCNT2_5
#undef TCNT2_6
#undef TCNT2_7
#undef OCR2A
#undef OCR2_0
#undef OCR2_1
#undef OCR2_2
#undef OCR2_3
#undef OCR2_4
#undef OCR2_5
#undef OCR2_6
#undef OCR2_7
#undef OCR2B
#undef OCR2_0
#undef OCR2_1
#undef OCR2_2
#undef OCR2_3
#undef OCR2_4
#undef OCR2_5
#undef OCR2_6
#undef OCR2_7

#define NUM_DIGITAL_PINS  30
#define NUM_ANALOG_INPUTS 12

#define TX_RX_LED_INIT	DDRD |= (1<<5), DDRB |= (1<<0)
#define TXLED0			PORTD |= (1<<5)
#define TXLED1			PORTD &= ~(1<<5)
#define RXLED0			PORTB |= (1<<0)
#define RXLED1			PORTB &= ~(1<<0)

static const uint8_t SDA = 2;
static const uint8_t SCL = 3;

// Map SPI port to 'new' pins D14..D17
static const uint8_t SS   = 17;
static const uint8_t MOSI = 16;
static const uint8_t MISO = 14;
static const uint8_t SCK  = 15;

// Mapping of analog pins as digital I/O
// A6-A11 share with digital pins
static const uint8_t A0 = 18;
static const uint8_t A1 = 19;
static const uint8_t A2 = 20;
static const uint8_t A3 = 21;
static const uint8_t A4 = 22;
static const uint8_t A5 = 23;
static const uint8_t A6 = 24;	// D4
static const uint8_t A7 = 25;	// D6
static const uint8_t A8 = 26;	// D8
static const uint8_t A9 = 27;	// D9
static const uint8_t A10 = 28;	// D10
static const uint8_t A11 = 29;	// D12

#define digitalPinToPCICR(p)    ((((p) >= 8 && (p) <= 11) || ((p) >= 14 && (p) <= 17) || ((p) >= A8 && (p) <= A10)) ? (&PCICR) : ((uint8_t *)0))
#define digitalPinToPCICRbit(p) 0
#define digitalPinToPCMSK(p)    ((((p) >= 8 && (p) <= 11) || ((p) >= 14 && (p) <= 17) || ((p) >= A8 && (p) <= A10)) ? (&PCMSK0) : ((uint8_t *)0))
#define digitalPinToPCMSKbit(p) ( ((p) >= 8 && (p) <= 11) ? (p) - 4 : ((p) == 14 ? 3 : ((p) == 15 ? 1 : ((p) == 16 ? 2 : ((p) == 17 ? 0 : (p - A8 + 4))))))

//	__AVR_ATmega32U4__ has an unusual mapping of pins to channels
extern const uint8_t PROGMEM analog_pin_to_channel_PGM[];
#define analogPinToChannel(P)  ( pgm_read_byte( analog_pin_to_channel_PGM + (P) ) )

#ifdef ARDUINO_MAIN

// On the Arduino board, digital pins are also used
// for the analog output (software PWM).  Analog input
// pins are a separate set.

// ATMEL ATMEGA32U4 / ARDUINO LEONARDO
//
// D0				PD2					RXD1/INT2
// D1				PD3					TXD1/INT3
// D2				PD1		SDA			SDA/INT1
// D3#				PD0		PWM8/SCL	OC0B/SCL/INT0
// D4		A6		PD4					ADC8
// D5#				PC6		???			OC3A/#OC4A
// D6#		A7		PD7		FastPWM		#OC4D/ADC10
// D7				PE6					INT6/AIN0
//
// D8		A8		PB4					ADC11/PCINT4
// D9#		A9		PB5		PWM16		OC1A/#OC4B/ADC12/PCINT5
// D10#		A10		PB6		PWM16		OC1B/0c4B/ADC13/PCINT6
// D11#				PB7		PWM8/16		0C0A/OC1C/#RTS/PCINT7
// D12		A11		PD6					T1/#OC4D/ADC9
// D13#				PC7		PWM10		CLK0/OC4A
//
// A0		D18		PF7					ADC7
// A1		D19		PF6					ADC6
// A2		D20 	PF5					ADC5
// A3		D21 	PF4					ADC4
// A4		D22		PF1					ADC1
// A5		D23 	PF0					ADC0
//
// New pins D14..D17 to map SPI port to digital pins
//
// MISO		D14		PB3					MISO,PCINT3
// SCK		D15		PB1					SCK,PCINT1
// MOSI		D16		PB2					MOSI,PCINT2
// SS		D17		PB0					RXLED,SS/PCINT0
//
// TXLED			PD5
// RXLED		    PB0
// HWB				PE2					HWB

// these arrays map port names (e.g. port B) to the
// appropriate addresses for various functions (e.g. reading
// and writing)
const uint16_t PROGMEM port_to_mode_PGM[] = {
	NOT_A_PORT,
	NOT_A_PORT,
	(uint16_t) &DDRB,
	(uint16_t) &DDRC,
	(uint16_t) &DDRD,
	(uint16_t) &DDRE,
	(uint16_t) &DDRF,
};

const uint16_t PROGMEM port_to_output_PGM[] = {
	NOT_A_PORT,
	NOT_A_PORT,
	(uint16_t) &PORTB,
	(uint16_t) &PORTC,
	(uint16_t) &PORTD,
	(uint16_t) &PORTE,
	(uint16_t) &PORTF,
};

const uint16_t PROGMEM port_to_input_PGM[] = {
	NOT_A_PORT,
	NOT_A_PORT,
	(uint16_t) &PINB,
	(uint16_t) &PINC,
	(uint16_t) &PIND,
	(uint16_t) &PINE,
	(uint16_t) &PINF,
};
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

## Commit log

2013-05-28 Feintuning damit es auch in der Arduino IDE laeuft
2013-05-28 Arduino IDE Umgebung, gleiche Sourcen bis auf microSRCPGL welche nach pde umbenannt und Anpassen der Includes
2013-05-28 Angepasst an Arduino IDE inkl. Ausgabe von Debugging Informationen
2013-05-29 Serieller I/O aktiviert, Servo Adressen korrigiert
    [microSRCPGL.cpp]
2013-05-29 Servo Adressen korrigiert
2013-05-29 Log zum RocRail Trace
2013-05-29 Detailkorrekturen - Servo schaltete nicht, Led falsch herum angesteuert
2013-06-01 I2C Grundgeruest
2013-06-01 Protokoll wird jetzt mittels #define eingestellt, erspart mehrere Sketches.
2013-06-01 getDescription fuer I2C Bus implementiert
2013-06-01 I2C Grundgeruest - nicht getestet
2013-06-02 I2C Umbau - 1. Teil
2013-06-02 Korrekturen und Tests fuer I2C Schnittstelle
2013-06-03 Totalumbau I2C Adressierung der lokalen Geraete
2013-06-03 I2C Bus Feinschliff und Tests der Geraete
2013-06-03 Sensoren werden nur noch alle 500 Millis abgefragt, weniger Trafik auf dem I2C Bus
2013-06-03 Revert "Feinschliff"
    This reverts commit b7f99655d7eff1f953f46f5b50a3e4c23fd93f71.
    [microSRCPGL.cpp]
2013-06-03 DCC Board - Alpha Variante
2013-06-03 Beispiel fuer ein I2C Slave Board
2013-06-03 Sketch inkl. Libraries fuer DCC Board
2013-06-03 Anpassungen an Arduino IDE
2013-06-05 Trace RocRail - Arduino
2013-06-05 Kombination OpenDCC Code und microSRCP
2013-06-05 Minimales Beispiel fuer das lesen und behandeln von SRCP Befehlen
2013-06-05 Einfaches SRCP Beispiel erweitert um Led's und Servo
2013-06-06 I2C Beispiel
2013-06-06 Beispiel I2C Verkabelung
2013-06-06 GASignal funktioniert jetzt mittels Adresse und Port = Led
2013-06-06 refresh() ueber alle Geraete auch GA und GL Beispiel fuer eine blinkende Led unter Verwendung von refresh()
2013-06-07 Geraet fuer langsamen Servowechsel
2013-06-08 Anfangsruckeln eleminiert An- und Abschalten des Servos wenn nicht gebraucht
2013-06-08 Es gibt nur noch die Core Sourcen unter microSRCP/arduino/libraries - microSRCPCore/src linkt dorthin
2013-06-10 Optimierungen fuer Raspberry PI
2013-06-10 SRCPEthernetServer umbenannt und verschoben nach lan - um Probleme mit Arduino IDE 1.0.1 zu vermeiden
    [microSRCPDCC.ino, microSRCPGAWave.ino, microSRCPODCC.ino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]
2013-06-12 Klarstellungen bei Namen um Konflikte zwischen ODCC und DCC zu vermeiden
2013-06-12 Sourcen sind nur noch in arduino/libraries
2013-06-12 Anzeige freeRAM in INFO POWER Meldung
2013-06-12 I2C Bus - delay vermindert wie alte Version 10 millis lesen und 5 millis schreiben
2013-06-12 Beispiel Motorentreiber
2013-06-12 Umbau Motor Shield - Variante 1
2013-06-13 MotorenShields Geraete bereinigt
2013-06-14 Neuer Board Layout - basierend auf einer Eigenentwicklung
2013-06-14 Variable Angaben von Anzahl I2C Slaves und Sensor Polling eingebaut
2013-06-14 Falscher Default Wert fuer die Kommunikation
2013-06-15 Beispiel fuer weitere Board Layouts
2013-06-16 Falsche FB Startadresse, korrigiert
    [microSRCPServer.cpp]
2013-06-16 Neues GL Board
2013-06-16 Beide DCC Varianten funktionieren jetzt auch als I2C Slave
2013-06-20 Ausgabe der Geraete vereinheitlicht und als Makro implementiert
2013-06-20 Meldungen fuer den I2C Bus optimiert
2013-06-20 Langsame Servo Ansteuerung ist jetzt Standard
2013-06-21 RaspBerry Pi Einstellungen und Installationsanweisungen
2013-08-17 Es wird das Analog Hilfsregister statt das I2C Register als Zwischenspeicher fuer OpenDCC verwendet
2013-08-22 Konfigurationsdateien fuer RaspberryPi als WLAN Access Point
2013-08-26 Mehr Details zu RocRail, Firmata und fhem
2013-08-30 Haftung und abgestimmte Verwendungsmoeglichkeiten
2013-08-30 PDF/A Format damit es auf OS/X auch sauber angezeigt wird
2013-09-08 Detailkorrekturen und neue Folien - Elektronik 1 x 1 - DCC
2013-09-09 Folie mit Hausautomation und 220 Volt
2013-10-03 Falsche Pin Bezeichnungen im Kommentar bereinigt (C0-C3 = A0-A3)
2013-10-07 Raspberry Pi Vorlagen und Konfigurationsdateien
2014-03-28 Kurzvorstellung microSRCP und microHOME - OSS an Schulen
2014-04-25 Kurzvortrag ictScope wie Messen wir das Internet der Dinge
2014-04-25 Beispiele zu Kurzvortrag wie misst man das Internet der Dinge
2014-05-30 microSRCP Shield
    [microSRCPShieldV1.brd, microSRCPShieldV1.sch, microSRCPShieldV2.brd]
2014-06-14 Schaltplaene und Layout von eigenen Shields
    [microSRCP-RaspiV1.brd, microSRCP-RaspiV2.brd, microSRCPShieldV1.brd]
2014-07-28 microSRCPV2 Board und Sketches
    [microSRCPV2.fzz]
2014-07-28 Korrektur Beschriftungen - LED's
    [microSRCP-RaspiV2.brd]
2014-07-28 Konfigurationsdatei wird nicht benoetigt
2014-08-16 microSRCP Shield mit Steckern an allen Pins
    [microSRCPShieldV3.brd]
2014-08-16 Gerber Files raus
2014-08-16 V3 mit gleicher Pin-Belegung wie V2 plus SPI Anschluessen
    [microSRCPShieldV3.brd]
2014-08-17 Massenflaechen angefuegt
    [microSRCPShieldV3.brd]
2014-08-17 Shield fuer Arduino Pro Mini - von www.betemcu.cn
    [microSRCPProMiniV3.brd]
2014-08-31 Ansteuerung MAX7219 LED Driver
2014-10-01 I2C Register statt Analog Hilfsregister verwenden.
    Durch die Aenderung vom 17. August 2013 funktionierten einige Decoder
    nicht mehr.
2014-11-12 L298N motor driver board module
2014-11-12 Power ON und OFF waren vertauscht
2014-11-15 Unterstuetzung fuer Arduino MEGA
2015-08-01 Problematik mit zwei oder mehr Zentralen geloest
    Werden zwei Zentralen an der Seriellen Schnittstelle angeschlossen, wird
    bei unterschiedlichen Arduino's die schneller Zentrale nicht sauber
    initialisert. Das aeussert sich dadurch, dass bei der ersten Zentrale
    keine Rueckmelder gemeldet werden.

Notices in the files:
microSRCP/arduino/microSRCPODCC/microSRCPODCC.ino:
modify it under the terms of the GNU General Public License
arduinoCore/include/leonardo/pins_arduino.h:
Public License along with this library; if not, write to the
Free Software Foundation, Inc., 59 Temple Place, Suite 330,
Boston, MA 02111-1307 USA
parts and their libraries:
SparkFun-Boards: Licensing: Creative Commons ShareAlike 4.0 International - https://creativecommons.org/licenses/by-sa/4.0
